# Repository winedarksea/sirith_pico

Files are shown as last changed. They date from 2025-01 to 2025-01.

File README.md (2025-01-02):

# Sirith Pico
#### Designed by Colin Catlin
#### License: CERN Open Hardware Licence Version 2 - Weakly Reciprocal
I ask only that you attribute me if you do make anything awesome with it, and more importantly, share with me as I would love to see others putting my hard work to good [use](https://syllepsis.live/2025/01/02/autonomous-ambush-missiles-and-my-first-circuit-board/). Feel free to reach out with any issues you run into.

This board was designed to do something standard dev boards cannot do: provide high power (12V, 60W) output with a microcontroller and a powerful rechargeable battery. It was designed to power something like a Raspberry Pi Zero, manage an array of servos, contain basic sensor data, log data to an SD card, and send and switch high power off board.

As a number of the ICs on this board are rather expensive, there is also a fairly extensive focus on circuit protections for power sources and GPIO pins, with the aim of reducing the probability of damage to the board.

This board went through countless digital versions, two expert reviews, and no less than 7 production variants. It was made by an amateur, but the design is well tested at this point. Amateur EMI testing was also done and indicated no major sources of unintentional radiation from the board.

Recommendations: switch the Fuse block on the "Batt Out" to PTC resettable fuse(s). The current fuses seem to not always contact the mounts fully.

Highlighted Capabilities:
* USB C Power Delivery Input up to 60W by default
* 2S or 3S Lipo Power and Charging
* Regulated and adjustable 8V or 12V system power
* Regulated 5V, 3.3V, and 1.8V power supply output
* User controllable output for high amperage output directly from battery*
* User controllable outputs for regulated system and 5V power
* Integrated i2c power monitoring circuit
* Integrated SD Card mount
* RP2040 Dual Core Microcontroller with 16 MB of flash memory
* IMU, Magnometer, Barometer
* RTC (if present)
* User-controllable status LEDs
* Pin layouts for connecting 4x 5V servos and 4x high voltage servos
* One 5V level shifted GPIO pin for communicating with devices such as LED light strips
* Footprint for Xiao or QtPy footprint boards for integration of wireless connectivity via UART to RP2040 (add on board not included)
* Integrated protection circuits on most system inputs and outputs
* Qwiic compatible connections of easy integration of other boards
* Assortment of board mounting options for 50 mm * 158.25 mm board

Primary Integrated Circuits (IC):
* RP2040 - primary microcontroller (MCU)
* MAX77960 - battery charger and system voltage regulation
* MPM54304 - 5V, 3.3V, and 1.8V buck regulator
* CYPD3177 - usb pd policy negotiations

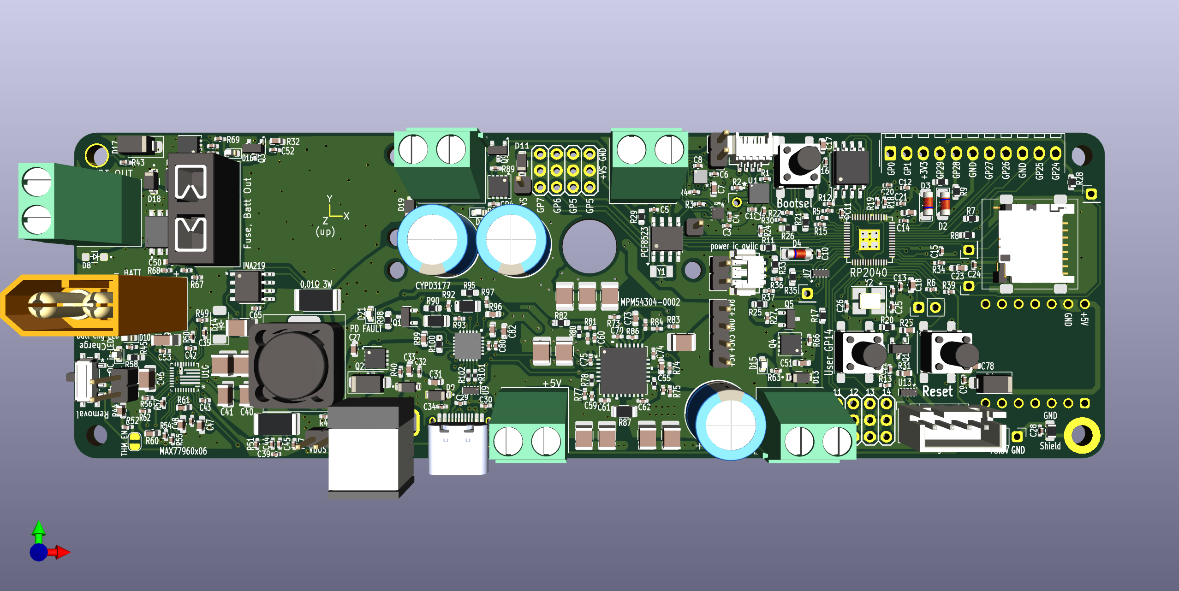
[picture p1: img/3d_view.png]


Note that by default interrupt pins are not directly connected to the RP2040 MCU in any way.

View documentation of the RP2040 from the Raspberry Pi Foundation for additional details on connecting peripherals and for excellent example tutorials.

MOSFET Power Outputs are connected to unidirectional TVS diodes which should provide inductive flyback protection in addition to transient overvoltage protection. The VBatt FET is additionally connected to a second Schottky diode for increased flyback protection.

For experimentation, it is recommended to begin by using GPIO 7, 28, and 29 as the series resistors and 3V3 Zener Diodes should prevent damage to the MCU from occurring in the event of many common misconfigurations and misconnections. 3V3 Zeners do not exactly maintain 3V3 volts, around 3.1V is often measured with the default GPIO pull up. These zeners may slightly alter the voltage and therefore ADC usage of GPIO28 and GPIO29. Note the 5V TVS diodes breakdown voltage is approximately 8V, these will be less protected than Zener diodes but also less restrictive.

For brevity, pins on the board are labeled GP instead of GPIO or only the number may be provided (ie 11 = GP11 = GPIO11). This should be considered functionally identical.

### System Power:

Primary system power delivery is through the device’s USB-C port. This port provides both data connection to the RP2040 IC as well as device power.  The CYPD3177 device is preconfigured by resistor dividers to negotiate for the highest available voltage up to 20V and 3A. This device can also be configured over i2c from the RP2040 MCU. If the device is only able to negotiate 5V power, the USB default standard power, the LED designated PD FAILURE on the board will be lit.

Power may also be provided through a dc barrel jack (not included, XXX has been used). If both dc barrel and usb c power sources are available, the higher voltage power source will automatically be used. This feature has been shown with limited testing to work for alternating between a 12V rated (~20V open circuit) solar panel and a 5V usb power supply.
Max recommended input is a well-behaved 24V power supply. Voltages above around 25V may  see the TVS over voltage protection beginning to conduct small amounts of power.

There are empty footprints under the DC barrel port for the addition of an LED and a series resistor, both 0803. This can be used to indicate power okay for this DC input and may also be useful to help pull down the open circuit voltage of any connected solar panels, if used.

A small test point header labeled VBUS should show the chosen power supply’s input voltage that will be received by the MAX77960.

### Battery Management

The MAX77960 provides battery charging and system voltage regulation with many inclusive features such as overcurrent protection and thermal shutdown. By default this is configured to use a 3S Lipo (three cell lithium batteries usually labeled 11.1V) with a regulated system max voltage of 12V and system current of 4 amps. By soldering the CNFG JP6 jumper on the bottom of the board, users may switch to a default configuration to 2S (two cell lithium batteries usually labeled 7.4V) at 8V system. The device WILL NOT automatically detect battery type. Connecting the incorrectly configured battery type may result in catastrophic battery failure. To double check the system’s current battery configuration, connect device without battery to DC power and use either the onboard INA219 or a voltmeter to measure Vsys. It should be around 8V in 2S configuration and around 12V in 3S configuration. Please refer to the MAX77960 datasheet for full details.

A sliding switch provides a battery disconnect override. The recommend procedure for battery connection using the XT60 connector is to have the switch in the disconnected position, insert battery, and then slide to charging position. To disconnect, perform in reverse first setting to disconnect then removing the battery. Whenever possible, avoid disconnect of batteries and dc power supply when the system is under significant power load, doing so could cause the board to malfunction. Not this switch does not necessarily trigger immediate battery charging, it merely signals charging enabled to the MAX77960 which proceeds to monitor battery and respond accordingly. While a battery is not needed for the board to function, including one will stabilize maximum power output of the device. In the event there are concerns about this switch accidentally being toggled, it can be removed leaving the device in a default state of battery charge enabled.

A small header labeled THM near the MAX77960 allows the connection of a thermistor. This is recommended if the device will be used in unregulated temperature environments as lithium batteries should not be charged in excessive heat or cold. To use, the THM_EN jumper must first be bridged. The R(resistance at room temp) value of the thermistor must match the value of the resistor R50, which is 10K. As setup, the pull down of ground, 110K on R41 will need to be removed for best accuracy, but should work as is (reading a bit hot). Beware if that resistor is removed a THM to GND thermistor must be present for device to function. In general, use a smaller Beta 10K NTC for a wider temperature cutoff. See MAX77960 datasheet for more info and example thermistor choices.

The INOKB output of the MAX77960 is connected to GPIO16 of the RP2040. This will be pulled low when a valid DC input is detected and can be used as a simple test for the presence of a connected external power source. The MAX77960 is also theoretically capable of reverse powering the USB C port with 5V power when configured to do so over i2c (off by default), but this functionality has not been tested on this board. STAT and INOKB pins from this device have test points on the bottom side of the board.

A pair of XXXX MOSFETs in parallel provide a high-side switchable output from the battery through a mini automative blade style fuse for overcurrent protection. While this has been designed with a target current output of 30 amps, extreme care should be and system monitored for shorts and excessive heating of the board gpiven the high discharge capacity of most lithium ion batteries. Also be aware that the board, which has a default fast charging current of 400 mA, will take much longer to charge the battery than the rate at which it can be discharged. Faster charging rates may be selected by adjusting RX or over i2c.

The system does not include a battery cell balancer. The use of a default 12V max voltage (approximately 80% of capacity) and a slow (for large batteries) fast charge rate of 400 mA should minimize the need for balancing, but cell balancing is still recommended when possible. 

A battery level gauge is also not included. When on battery power, the INA219 can be used to directly monitor the battery voltage and closely approximate battery level. As the default undervoltage protection for the system is lower than ideal, it is highly recommended that users relying on battery power for their systems power down their systems programmatically when a low voltage on the battery is reached to prevent possible battery damage.

Beyond the battery voltage, system regulated voltage (Vsys) from the MAX77960 passes through the INA219 current/voltage/power monitor with a 0.010 ohm resistor which can be read over i2c. Overcurrent protection kicks in after 4 amps but can be configured in the MAX77960 by i2c to be as high as 10 amps. Vsys will follow battery voltage when battery is charging or discharging.

The Vsys has another high side, GPIO-controlled MOSFET switch which can be used to enable or disable power output to an external device. Vsys also has placement for additional bulk capacitance to be installed by the user if needed, to further reduce volatility of the output power.

Vsys has several output connections. Note GPIO5 pin in this section is intentionally duplicated, allowing for synchronous output if needed.

The MPM54304 is powered from Vsys and produces additional regulated power outputs. Note that this IC is the usually hottest on the board, and that care and an additional heatsink is recommended. Note that the device does include automatic thermal shutdown in the event of excessive heat generation but this does not engage until 160°C. Additionally, running the system on a 2S battery setting will reduce heating as the voltage drop will be lower, and this is recommended when a 3S battery is not otherwise needed.

Theoretical max power output o MPM54304 is 6A for 5V, 3A for 3V3 and 3A for 1V8, however this may be limited further by the maximum continuous power dissipation due to thermal limits. To maximize performance, provide a larger heatsink and use a lower input voltage (2S configuration). For further details review the manufacturer’s datasheet for the MPM54304.

It is recommended to have inline resistors or PTC fuses on power lines going off board, especially on the 3V3 line which controls the MCU, to avoid brownouts from external shorts, as the overcurrent protection on the MPM54304 will take down the entire power net in the event of a short. The Power Good pin from this IC is connected to a circular test point on the bottom of the board.

### Board Footprint

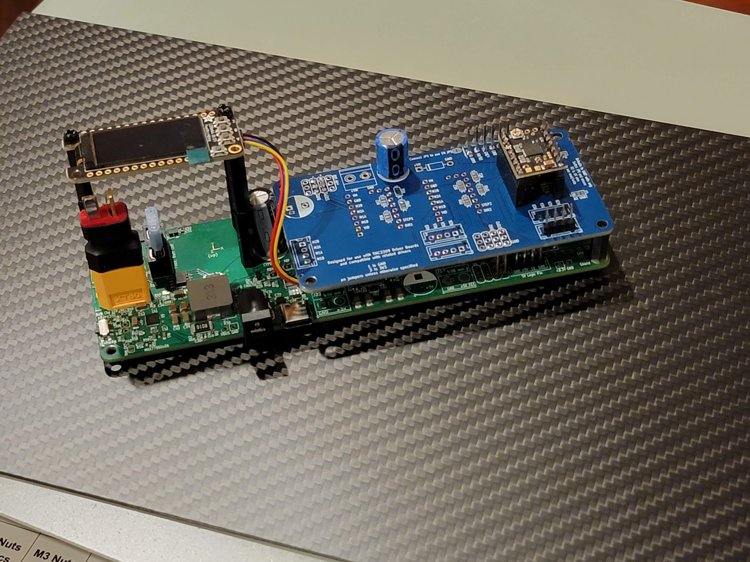
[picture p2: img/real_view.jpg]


The four layer printed circuit board measures 50 mm * 158.25 mm. Mounting holes for M3 screws are present on all four corners. The connections of these are rather irregular. Two are unplated through holes with no copper connection. Two others are plated through holes which should provide more resistance to wear and tear. One, located in the VBat section of the board, is connected to board ground by a 1M Ohm resistor. The other in the opposing corner near the QTPy/Xiao footprint is connected to ground by a capacitor with an adjacent footprint for an additional capacitor, resistor, or ferrite bead if desired, that plated through hole is also connected to USB shield, if present.

### QTPy/Xiao

A footprint designed to be compatible with most Adafruit Industries QTPy or SeeedStudio Xiao layout development board exists on the bottom of this board primarily intended for adding some wireless connectivity, if desired. These devices may be soldered directly or using pin headers, double checking proper alignment. Only four pins of the attached board are connected to the MCU. 5V power provides power to the 5V/USB power of the device through a Schottky diode, resulting in a minor voltage drop (no issues have been observed as result of this voltage drop) and allowing simultaneous connecting of the smaller board with USB. GND is also connected as well as the TX and RX pins of the device enabling communication with pins 24 and 25 of the RP2040 (see Table 1).

### Programming the Board

Programming the board should be identical in most ways to programming a Raspberry Pi Pico. BOOTSEL is held down while the device is plugged into the USB port of a host device to allow installation of UF2 boot files on initial setup. All UF2 files compatible with Raspberry Pi Picos should be compatible with this device, although note that pin aliases in the device software, such as “LED” pin will not align with a board LED.

### i2c addresses
* 0x08 = CYPD3177
* 0x3C = display, if connected
* 0x40 = INA219
* 0x68 = MPM
* 0x68 = RTC
* 0x69 = MAX probably

* 0x68 = RTC
* Ox77/Ox76 = BMP390
* 0x1C = LIS3MDL
* 0x6A = LSM6DSOX

### Table 1: GPIO Functions
| **Pin/Output**  | **Functions** | **Onboard Protections/Connections** |
| --- | --- | --- |
| RP2040 GPIO 0 | General purpose, labeled TX | 27 Ohm series resistor |
| RP2040 GPIO 1 | General purpose, labeled RX | 27 Ohm series resistor |
| RP2040 GPIO 2 | I2C 1 SDA for Sensors, ‘sense qwiic’ | 27 Ohm series resistor, 4K7 Ohm pull-up to 3V3 |
| RP2040 GPIO 3 | I2C 1 SCL for Sensors, ‘sense qwiic’ | 27 Ohm series resistor, 4K7 Ohm pull-up to 3V3 |
| RP2040 GPIO 4 | Enables Vsys MOSFET and LED when pulled high, | 330 Ohm series resistor, 1M Ohm pull down to GND |
| RP2040 GPIO 5 | Vsys header, duplicated with two positions on output header | |
| RP2040 GPIO 6 | Vsys header, single header | |
| RP2040 GPIO 7 | Vsys header, single header | 330 Ohm series resistor, 3V3 Zener to GND |
| RP2040 GPIO 8 | I2C0 SDA, ‘power ic qwiic’, connected to board power ICs | 27 Ohm series resistor, 4K7 Ohm pull-up to 3V3, 5V TVS diode |
| RP2040 GPIO 9 | I2C0 SCL, ‘power ic qwiic’, connected to board power ICs | 27 Ohm series resistor, 4K7 Ohm pull-up to 3V3, 5V TVS diode |
| RP2040 GPIO 10  | Enables 5V MOSFET/+5VF when pulled high, also with additional header near SD card enclosure, also can be used as status LED | 330 Ohm series resistor (between header and MOSFET, not between header and MCU), 1M Ohm pull down to GND, 5V TVS diode |
| RP2040 GPIO 11  | Header near system 5V outputs | 330 Ohm series resistor and 5V TVS for surge protection |
| RP2040 GPIO 12  | Header near system 5V outputs | |
| RP2040 GPIO 13  | Header near system 5V outputs | |
| RP2040 GPIO 14  | Header near system 5V outputs | Connected to button, can be programmed as an input |
| RP2040 GPIO 15  | 5V Logic Level GPIO, level shifted by BSS138 with 110K Ohm pull-up to 5V | 330 Ohm series resistor |
| RP2040 GPIO 16  | INOKB to MAX77960<br>pulls low when DC power present, floating when disconnected | |
| RP2040 GPIO 17  | Enables VBatt MOSFET and LED when pulled high | 330 Ohm series resistor, 1M Ohm pull down to GND |
| RP2040 GPIO 18  | CLK pin of SD Card | |
| RP2040 GPIO 19  | CMD pin of SD Card | |
| RP2040 GPIO 20  | DAT0 of SD Card | 10K pull-up to 3V3 |
| RP2040 GPIO 21  | DAT1 of SD Card, additional header near SD card when unused | |
| RP2040 GPIO 22  | DAT2 of SD Card, additional header near SD card when unused | |
| RP2040 GPIO 23  | DAT3/CD of SD Card | |
| RP2040 GPIO 24  | Two connections, to header and to RX of QTPy/Xiao footprint, so is TX of MCU when used | 330 Ohm series resistor |
| RP2040 GPIO 25  | Two connections,to  header and to TX of QTPy/Xiao footprint, so is RX of MCU when used | 330 Ohm series resistor |
| RP2040 GPIO 26  | Header | |
| RP2040 GPIO 27  | Header | |
| RP2040 GPIO 28  | Header | 330 Ohm series resistor, 3V3 Zener to GND |
| RP2040 GPIO 29  | Header | 330 Ohm series resistor, 3V3 Zener to GND |
| SWDIO and SWCLK | Debugging connections for RP2040 | |
| INT | Connection to interrupt pin from device IMU | |
| INT MAG | Connection to interrupt pin from device manometer | |
| INT/CLKOUT | Connection to interrupt/clkout pin from device RTC, if present | |

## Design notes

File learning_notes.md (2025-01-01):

## Loosely Collected Notes I took as I learned circuits and designed this board

Servo Controller (ala Adafruit) 
	PCA9685
	tlc59116
	use a pi pico or similar, but more programming work
Servo Battery
	ETA9740, HM5907
	6V 4A regulated power supply to protect servo
		Boost converter or regulator (5V to 6V with a resistor)  (TI has a bunch)
	Include 5V power
	Includes 3.3 V power
Servo battery charger
	TPS61230 (5A)
	TPS61090 (2A)
	https://wiki.seeedstudio.com/Lipo-Rider-Plus/
	2S BQ25887 2S Balance charging IC
USB-c wiring:
	the correct pulldowns for CC1 and CC2 are 5K1, You do need separate pulldowns for each CC pin
	DP and DN should go straight to the data controller (potentially with ESD protection diodes).
	There should be no more than 10uF of capacitance on VBus, and you have to make sure your circuit draws no more than 100mA until:
    1. you negotiate more through power descriptors (up to 500mA)
    2. you see appropriate voltages on the CC lines
    3. you detect either a DCP or CDP using BCS
	https://dubiouscreations.com/2021/04/06/designing-with-usb-c-lessons-learned/
	It looks like I should have fed CC1 and CC2 to two adc pins to handle connector polarity.
	Basically, if you see >1.23V on either CC1 or CC2, you are all set and can draw 3A. If it's between 0.66V and 1.23V you can draw 1.5A. Put a filter on the CC lines because there will be some fluctuations (up to 10ms long) that you are supposed to ignore.
	You need to also verify the IC connected to the UDP pin has an internal pull up to 3.3V, or add an external resistance.
	Suggestion seemed to be capacitor placed as close as physically possible to power output pins.
	Shield should not be connected to the ground, but the chassis.
	USB 2.0-only SMT Korean Hroparts TYPE-C-31-M-12 (LCSC part number C165948)
	Pico USB_DM and USB_DP A 27Ω series termination resistor is required on each pin, but bus pullups and pulldowns are provided internally
Voltage Regulation
	USB SHIELD: 1MΩ resistor and 4.7 nF capacitor in parallel  OR (330 Ω resistor and a 0.1 µF capacitor in parallel)
	213716 Molex USB C
	AP2112  (input to 3.3V)  OR identical Torex XC6210B332MR-G

For 1S Lipo: MCP73871

MCP73213 or MCP73223 would require 2 LDO (one for USB one for battery)
JST-XH 2S
bq241xx  (rather complicated wiring)

Ultra Librarian or SNAPEDA

4.7K resistor on SDA and SCL for high speed operations  (2K fine, probably better if some are expected on upstream board)
Capacitors. Near each power line for IC.The value it is not very critical and usually it is at the range of 0.001μF to 4.7μF, but the combination of values helps to keep the impedance low and to avoid resonance spikes. 100nF and 10uF

Absolute Orientation Sensor
	BNO055 BNO08X (not in stock?)  (2.4 to 3.6V)
		0x29 (Com3 adjusts to 0x28)

qwiic connector  (JST SH 4-pin connector and will only use it for I2C)
	servo and absolute orientation sensor

Altimeter
	Bosch BMP390  (1.2 to 3.6V)
		SDO to GND results in slave address 1110110 (0x76); connection it to VDDIO results in slave address 1110111 (0x77)

https://www.nxp.com/design/designs/kv-series-quad-motor-control:KINETIS-DRONE-REFERENCE-DESIGN
https://www.nxp.com/design/designs/ai-robot-platform-based-on-i-mx-8m-plus:AI-ROBOT-PLATFORM
https://www.nxp.com/design/designs/px4-robotic-drone-vehicle-flight-management-unit-vmu-fmu-rddrone-fmuk66:RDDRONE-FMUK66
https://www.ti.com/solution/drone-propeller-esc?variantid=17140&subsystemid=17313
https://www.ti.com/applications/industrial/motor-drives/overview.html
https://www.ti.com/solution/drone-propeller-esc?variantid=17141&subsystemid=17228

N-channel Mosfet to PWM (terminal block)  (high current switch)
	D is the thing being used (Power source -> thing used -> Mosfet -> sink)
	Gate is the PWM signal (R1 1k, C1 100u, R2 10k)
	https://www.instructables.com/How-to-Control-a-MOSFET-With-Arduino-PWM/
	https://forum.arduino.cc/t/mosfet-control-with-pwm/912521/7
5 V Mosfet for powering on Vision board
Mosfet with no voltage (connecting RUN or GLOBAL_EN to ground)

Voltage of all on I2C ??
Addresses of all

Fiducial markers (for pick and place)

Include a charging LED (off when charged)

Wireless Receiver: SX1280
Add wifi ESP module

Battery linked to power switch
Microcontroller power on Vision Processor (what signal?) (GPIO pin 3, or serial message, RUN to ground)

RP2040 Chip
	USB_VDD should be decoupled with a 100nF capacitor close to the chip’s USB_VDD pin
	To reduce the number of external power supplies, ADC_AVDD can use from the same power source as the digital IO supply (IOVDD)
	ADC_AVDD should be decoupled with a 100nF capacitor close to the chip’s ADC_AVDD pin
	(all of the above and more to the same 3.3V)
	IOVDD should be decoupled with a 100nF capacitor close to each of the chip’s IOVDD pins.
	DVDD should be decoupled with a 100nF capacitor close to each of the chip’s DVDD pins.
	A 1μF capacitor should be connected between VREG_VIN and ground close to the chip’s VREG_VIN pin
	USB 2.0 compatible Full Speed device (12Mbps)

Mount points (for vibration dampening)

Microcontoller Connections:
	Two buttons (any pin, pwm)
		servo latch
	1 serial to MCU
		send data, receive updated target
	8 MB SPI FLASH (or larger) (QSPI NOR memory)
		Winbound W25Q16  W25Q16JVSSIM
	12 MHz crystal for perfect timing
	USB (same both for charging lipo and serial)
	BOOTSEL button while plugging it into USB (or pulling down the RUN/Reset pin to ground)

Pico Alternatives:
	STM32F779AIY6TR
	MSP432P411xT / MSP432P401xT
	nRF5340
	Kinetis® KV4x family - MCU for motor control
		MK20DX32VLH5 MKV42F128VL

Future Directions:
LoRa
DC input to Charge Lipo and to Power board (if connected)
	5V 2A switching regulator for robust power supply (8V -18V input voltage)

Suppliers:
	JLCPCB
	PCB Shopper
	PCBWay
	SeeedStudio
	Smart Prototyping
	PCB Shopper - see all

Reflow Oven:
	Breville Smart Oven
	T-962 https://www.aliexpress.com/item/2251832137689249.html?gatewayAdapt=4itemAdapt 
	ZH2520HL (needs 110V) https://zbdz.en.alibaba.com/product/62345546771-915115390/Smt_Reflow_Oven_For_IC_Chip_Mini_Reflow_Soldering_And_Welding_Oven.html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 

BGA makes assembly much more expensive

Actual Part List:
	USB4085-GF-A
	JST B3B-XH-AM(LF)(SN)  (right angle S3B-XH-A(LF)(SN) out of stock)
	Resistors 0603 (larger allows routing UNDER)
		5.1K  - 2
		R0 (no resistance)

	BATT CHARGER 
reqs: 
	2S or 3S Lipo (3s preferred)
	VIN Min < 5V
	VIN Max > 20V
	Current > 5 Amps
options:
	MP2650/MP2760  (unavailable)
	MP2762A (2s only)

	MP2639AGR-Z (QFN)
	MP2672A or MP2639A (QFN) or MAX14748 (non stocked)0x0A, integrates CC negotiation) or MAX77962 (0xD2h/0xD3h) or TI bq25792 (QFN) 		
	bq24179 (not stock)
	bq25887 (best stock, psel for detection), bq25883, bq25882, bq25886 (~886 best but not stocking, detects BC1.2)
	ACT2861QI301 (good for 3 cell, QFN, available)
	BQ25792
	MAX77961 (3 cell, sys connection, QFN) (61 is 6A, 60 is 3A)

	STUSB4500 (WLSCP, no stock) or STUSB4500L (3A Max) or MAX77958 or TPS65987D or PTN5110 or UPD301C
		MAX77958 is good but not QFN
	TPS65987D (QFN) (and similar tps65983 but external switch for 5A)
	XPD319BP25 (36W)

	BHI260AP (LGA 44 pin, 1.8V)  BHI160 (LGA 24 pin, 1.6 to 3.6V	)
	BMP390/BMP384/BMP581 (LGA 10 pin, 1.6 to 3.6V)
	BMM150 (WLCSP-12, 1.6-3.6V)
	BNO086, FSP200 (similar or same as Bosch, low stock)
	ICM-42688-V(QFN package, no sensor fusion)
	ICM-20948 (no stock, QFN, sensor fusion included but questionable)
	ISM330DHCX + LIS3MDL (6+3 axis, LGA, industrial, low stock) - add magnetometer and rp2040 for Fusion calculation

	PWM Controller PCA9685 (), TLC59116F (VQFN or TSSOP), TLC5947 (RGB LED Drivers)TLC59711, TLC5940, TLC5946, TLC694x, TLC59711 
		TLC5971, LED6001, MAX16803, RT9288A, LT3595A and LT8500, tlc59282 (all at once driver)
		LT8500 and TLC5940 are confirmed motor control,
		Dedicated Pi Pico (16 bit) - https://www.waveshare.com/w/upload/0/06/Pico_Servo_Driver_Sch.pdf 
		STNRG388A

	MOSFET: PMPB10XNE PMPB11EN CSD18542KTT

	BUCK
		All in one: lm5127, ADP1034/ADP1031, ltc7811/7818/7817, 
		tps65310a (2A limit, no stock),
		tps65287 (low stock, uncertain voltage setting but likely 3 buck),
		MAX20028 (only one > 4V, moderate stock), 
		MPM54304 (non over 5.5V, LGA, moderate stock)
		NCV97200 (3.3 and 5V only, no stock)
		ADP5055 (high current, LGA, moderate stock, 18V max)
		MC34VR500 (QFN, moderate stock)
	Plain BUCK
		MAX17504 (3.5A wide voltage)
		MAX17541G (0.5A)
		LMR16006
		TPS65320D-Q1 (buck + loo)
		MP2223 (dual output buck)
	Tps54331, MAX20028, MPM54304, TPS54620 (6A, in stock)

	DC Motor Driver: TB6612, DRV8871, L293D, L9110H, MX1508 (make pi), DRV8840, DRV8313, UCC27200A
	L298N, L293D, SmartElex 15S, VNH2SP30, VNH3ASP30, TB6612FNG, TB67H450FNG, L6258, HR8825
	FROM 3D Printers: TMC2209, TMC2130, TMC2225
	https://learn.adafruit.com/assets/9536
	https://www.ti.com/lit/ug/tiducn7/tiducn7.pdf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
	https://www.ti.com/tool/TIDA-00827#description 

https://www.mouser.com/manufacturer/amphenol-ltw/

JCLPCB In Stock:
	RP2040
	BMP388
	TMC2209
	BMM150
	BHI160B
	BQ7693003DBTR (Cell balancing)
	Bucks: TPS54331DR, MC34063ADR2G (1.5A), ICL7660AIBAZA-T
	LDO AMS1117-3.3 (3.3V fixed)
	Mosfets: AO3401A (max 12 V on gate, 4A), AO3400A (5.7A) P-channel,
	N-channel AO3402 (4A)
	USB PD-controller: XPD319 (DRP only), CYPD2120-24LQXIT
	PWM Controller: PCA9635, TLC5940 (no stock), TM1640, HT1621B
	Charger: MP26123DR
External:
	tps65987d
	TLC59401
	MAX77961EFV06+
	MAX17205

Used Datasheets:
y

Connectors:
neutrik
Phoenix Contact

Reqs:
47μF (1206 or 1210), 16V  GRM31CR61C476ME44, EMK325ABJ476MM8P
10 uF (0805), 16V  (Murata GRM32ER7YA106KA12)
10 uF (1210), 35V
220 nF   (0402), 6.3V
4.7 uF  (0402), 6.3V (10V on batt EVAL)
47 nF (0402) (25V on battery inrush) (Murata GRM31CR61C476ME44)
100 nF (0402), 10V  (>12V for batt)
22 uF (), 6V  GRM21BR61C226ME44 (overkill)
10 nF (25V on USB)
220 nF (on Inductor, low V, EVAL 0402)
22 pF (crystal, stable C0G class)

Mostly MLCC
X5R or X7R (especially on BATT charge and Converter for low ESR), although Class 1 is best
bigger size footprints generally are more stable with same temp coef
Anything on SYS, and BATT can be 16V MAX:   22UF (1210)
6V: 4.7uF (0603), 220 pF, 
33 pF (6V, Class 1)
47 uF (Sys, 2220)
VBUS, VD (PP_HV1) can be 30V MAX: 10 nF (0402), 1uF (0603), 10uF (1210), 47nF (0603)
Also 10uF 0603

3.3 uH  (16.3 mΩ resistance DC, 15 Amp, 10 Amp (+ 40C rise) (Pulse PA5007.332NLT)

0.01 Ω (1206), 3W
10 ohm (0402 on datasheet) 0.1W or higher
4.7 Ω (0402)
200K Ω (0402)

17800 (inlim)
86600 (iset)
178000 (ITO top off)
226000 (ITO top off)
178000 (set)
226000 (set 12.0 V)

Diodes
PMEG4050EP

LED: 19-217/GHC-YR1S2/3T

Mosfet
10A DMN3016LFDE DMN3020

Gate to Source should be 12V
for 5V: 5A is needed
for Sys: 10 A is needed
for Batt: 30A is needed

NOTES:
	Don’t unplug under load, either battery or DC power
	GP and GPIO are used interchangeably
	Use the batt removal switch
	This switch can be removed if there are concerns about accidentally sliding it to removal as the default is to charge (or remove what is currently R43, the pull up to AVL)
	Using a thermosistor - the R(resistance at room temp) value must match the value of the resistor R50 (currently 10K). As setup, the pull down of ground, 110K on R41 will need to be removed for best accuracy, but should work with (reading a bit hot). Beware if that resistor is removed a THM to GND must be present. See datasheet for more info and example thermistor choices. Use a smaller Beta 10K NTC for a wider temperature cutoff.
	Remove 10K on GP15 and bridge
	Fuses can be removed to slightly lower quiescent current or diodes can be desoldered
	can place heatsinks on square test pads
	avoid placing directly on conductive sheets as it will short test pads
	can use the vbus header to provide DC in if no USB power or USB out
	batt should be connected, it acts as an extra source of power for spikes
	batt can be kept in protective sleeve, but default charge is low current
	could use the places for capacitors on batt out and sys as locations for terminal blocks (caps on batt should have connections for high-ish amps, others maybe not so high)
	no batt balancing as default charge is slow
	no battery gauge!
	three sets of sda and scl i2c pins, all with pull ups to +3V3
	PP_HV2 has 5V supply theoretically capable of supplying/sourcing devices over USB, but by default this is disabled and on power loss will reset to sink mode
	battery low voltage
	all power chips have built in thermal shutdowns and overcurrent/undervoltage protections
	could replace the CNFG Resistor (currently R43) from 8660 (3S) to 86k6 (2s)
	Use on lead acid: https://www.ti.com/lit/an/slua992/slua992.pdf
	2 issues with RP2040: no floating point unit, no code security (use another board if those are needed for that and use this as a relay)
	INOKB is attached to GPIO 16 of the RP2040. This means this can be used to detect the presence of DC power on CHGIN when this is pulled low (and is pulled high when disconnected). Note that due to the default pull down of the RP2040, the test point for this will always register ground, just ground high resistance (>200K) with no chargin, and to low resistance to ground with charging present
	solar panel goes to high voltage (shutting off input from usb) even when there is little current available. The charger can sometime deal with this by regulating system voltage, but only if it has a battery connected for backup power.
	set i2c lines high to reduce current loss slightly (as they have 3.3V pull up resistors)
	set 5v logic pin high to reduce current loss
	swap current limiting resistor on 5V GP15 to get a high power data line (it’s bigger than its neighbors, an 0603 rather than 0402)
	Note the sum of current limiting resistors, if all were on, would still exceed the total current producible by the RP2040
	there is a lot of capacitance on this board, expect it to take a while (seconds) to fully turn off
	A high quality 3S lipo can theoretically produce something like 500 Amps, that is power that can be quite dangerous
	MOSFET max on DMP3007SCG is 50A continuous current and TPH3R704PL is 90A, Mini fuses are available up to 30A and the fuse block holder is rated to 20 Amps @ 500V AC, with all four layers (2x power, 2x ground) exclusively with power planes to hold the current on that corner of the PCB
	What is a safe temperature? In general components here have ratings provided for 70C with max ratings usually being higher. So that should be a guidance for what a safe ‘hot’ limit is. Lower, however, is definitely preferred as hot temperatures will likely result in a much short product lifespan
	The MPM will get less hot in 2S lipo mode (lower input voltage)
	Use temperature sensor to shut off charging if too hot
	can use a solar panel as dc input, keep in mind that panels rated voltage is often exceeded at open circuit, so 12V safest. Same with batteries, a ‘24V’ battery often has a nominal voltage as high as 30V
	So how much above 24V is a problem? See if the TVS diode near the barrel jack starts to get hot. TVS can repeated handle current in small amounts, but heat can damage it over time.
	square test points for heat sinks as needed
	Remove the voltage sensing resistor next to INA219 to further reduce power loss
	having inline resistors or PTC fuses in power going off board is a good idea, especially on the 3V3 line which controls the MCU
	LEDs are of varying brightness, batt mosfet is very bright (warning) while vsys mosfet is very dim
	Zeners may slightly alter the voltage and therefore ADC usage of GP28 and GP29
	The diode by the Vsys MOSFET could be removed for adding items there if desired
	Note on the two plated through holes, which should be preferred for connecting as they are more resilient. One connected to USB shield with option to connect to ground, the other connected to ground with 1M
	i2c line 1 (sensors) doesn’t have full ESD protection, although i2c0 does have 5V tvs (power ic qwiic)
	an LED and resistor (0805) may be placed on the bottom near DC in if a connection indicator is desired, or to pull down open circuit of a solar panel
	Place a diode (currently D15) between VBAT and VSyS to increase the possible current maximum
	Careful about using metal screws on the mounting holes as there are traces and planes fairly close to some of them. If screws are connecting to another board or metal enclosure, something conductive, keep an eye on them.
	Thinking about the supercap is that in the event of a power loss (probably a thermal overheat or overcurrent protection engagement) the MCU could continue to function (check for loss of connection to 5V powered INA219 for power loss)
	Theoretically MAX can be used to send reverse 5V OTG, if DC is not connected.
	Battery helps absorb inductive loads
Low Battery:
	Remove Diode and let Sys shut down automatically, adjust Sys min
	Set UVLO on MPM to 8.5 volts, and/or turn off 5V bucks (en1/2) but 
Note about Zeners and how they don’t hold exactly a stable 3V3 like you might hope. Yes, you can safely remove them (carefully, of course).
keep 3V3
	could pass 12V directly into VSYS (or indeed 5V to 16V)
	Stop performing actions on all outputs
	Use a timer since chg-in last connected
	DC in barrel has a TVS with a minimum possible breakdown of 24.4V
Possible substitutions:
	MAX 77960 (3A max charge in, 6A max sys)
	MPM54304GMN -XXX other suffixes (5V may be 2 separate nets, 3A max each)
	TPS25750 (would require some rework)
	Different RP2040 flash memory sizes
	Different switches, diodes, mosfets, inductor
	Any BMP38X, BMP581
Not populated if no equivalents available (all should be hand solderable):
	Fuse blocks
	SD card mount
	JST connectors
	Mounting holes changed
Pair with a ATECC608 breakout for code security, or use a code security feature on the Xiao/QTpy breakout spot

0x08 = CYPD3177
0x23 =TPS probably
0x3C = display, if connected
0x40 = INA219
0x68 = MPM
0x68 = RTC
0x69 = MAX probably

0x10 = BMM150
0x68 = RTC
0x68/Ox69 = BMI270
Ox77/Ox76 = BMP390

Uses:
	Uninterrupted backup power supply
	Boost power supply (where occasional spikes above USB power capability, legacy won’t cut it)
	Robots and automation of all sorts (ideal as sensors, unified power and mcu)

21.4 47.1
STEPPER BOARD
2 wire 16AWG standard cable
	either a AMP Mate-n-Lok 1-480424-0 power connector
	or PCIE or ATX 12V-only
	JST VH 4 pin (5v red, gnd, gnd, 12v yellow)
	molex sata 675820000
8 pin connector 
3x 5 screw terminal
Diodes:
https://learn.watterott.com/silentstepstick/protector/
https://www.autodesk.com/products/fusion-360/blog/trace-width/

Lessons:
	Use planes more than wires (although wires override planes and can help manage lane prioritization)
	Use the grid
	Use ‘Vendor’ for JCLPCB number in Kicad to export BOM easily
	voltage rating on capacitors should be 2x average expected
	use lots of capacitors (except on very high speed lines)

i2c pull-ups (those for I2C1 are not shown in image but are present) are to 3V3 power external and not to LDO_3V3 (assume this doesn’t matter but perhaps they need to be in a valid state at boot?)
LDO 1V8 has higher capacitance than recommend (max 6 uF, 10 uF used)
5V on PP_HV2
Pins 57, 58, and 59 for drain and grounds are labeled differently than data sheet (matching 59, 58, 57) but are correctly matched in layout

3V3 and 5VD come from a regulator and become available slightly after system receives power

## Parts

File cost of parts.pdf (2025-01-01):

PCB Prototype & PCB Fabrication Manufacturer - JLCPCB | https://cart.jlcpcb.com/smtQuote?pcbFileNo=1eeebdad9bf540228a708...

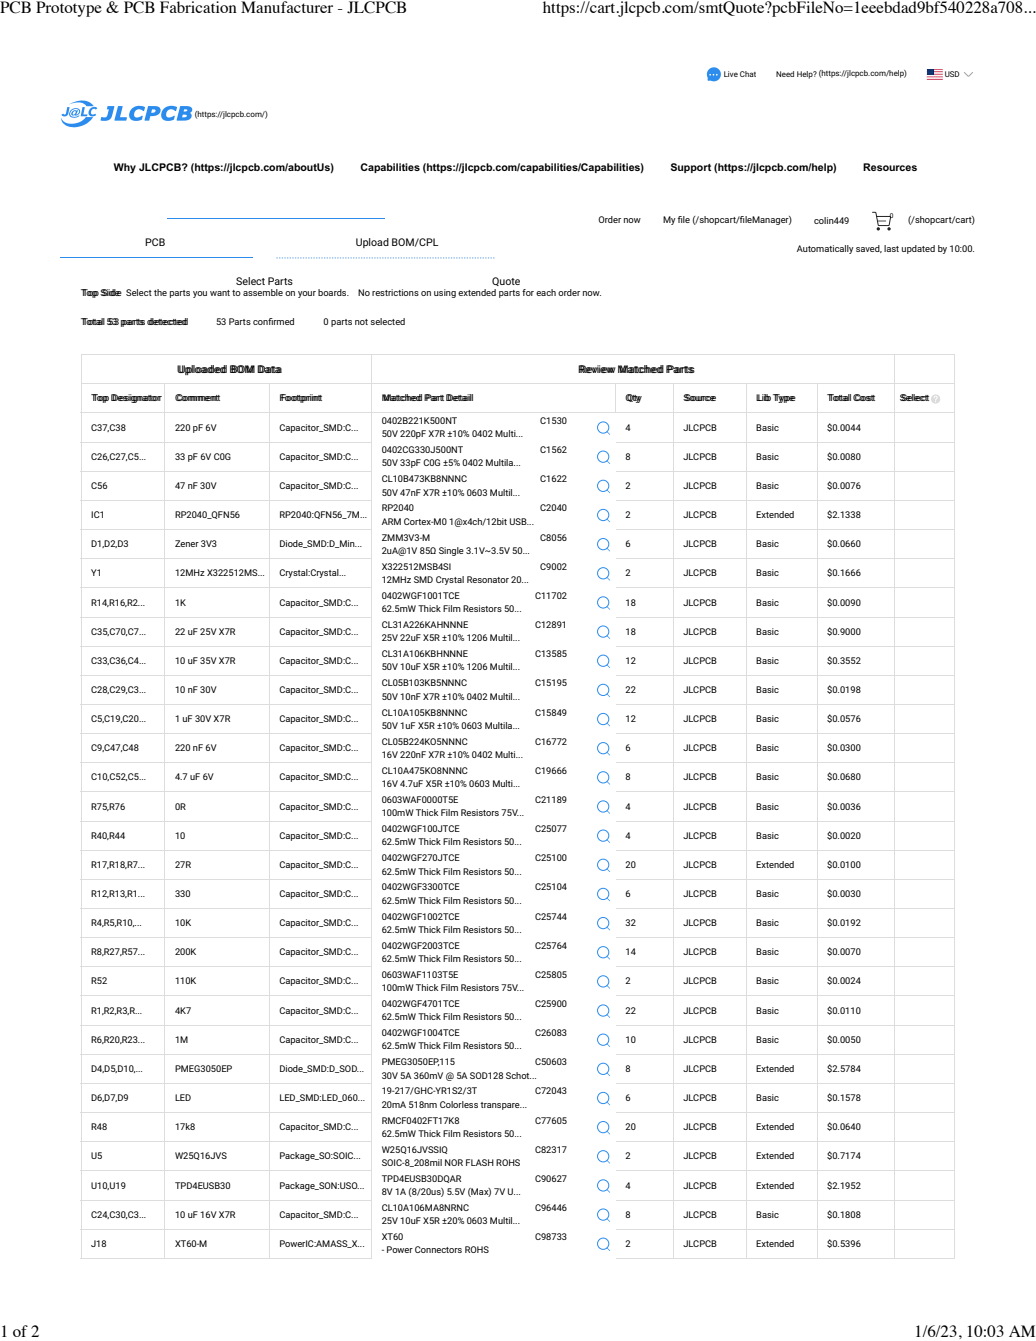
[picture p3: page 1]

Automatically saved, last updated by 10:00.

TToopp SSiiddee Select the parts you want to assemble on your boards. No restrictions on using extended parts for each order now.

Uploaded BOM Data | Review Matched Parts

Top Designator | Comment | Footprint | Matched Part Detail | Qty | Source | Lib Type | Total Cost | Select

C37,C38 | 220 pF 6V | Capacitor_SMD:C... | 0402B221K500NT C1530 50V 220pF X7R ±10% 0402 Multi... | 4 | JLCPCB | Basic | $0.0044

C26,C27,C5... | 33 pF 6V C0G | Capacitor_SMD:C... | 0402CG330J500NT C1562 50V 33pF C0G ±5% 0402 Multila... | 8 | JLCPCB | Basic | $0.0080

C56 | 47 nF 30V | Capacitor_SMD:C... | CL10B473KB8NNNC C1622 50V 47nF X7R ±10% 0603 Multil... | 2 | JLCPCB | Basic | $0.0076

IC1 | RP2040_QFN56 | RP2040:QFN56_7M... | RP2040 C2040 ARM Cortex-M0 1@x4ch/12bit USB... | 2 | JLCPCB | Extended | $2.1338

D1,D2,D3 | Zener 3V3 | Diode_SMD:D_Min... | ZMM3V3-M C8056 2uA@1V 85Ω Single 3.1V~3.5V 50... | 6 | JLCPCB | Basic | $0.0660

Y1 | 12MHz X322512MS... | Crystal:Crystal... | X322512MSB4SI C9002 12MHz SMD Crystal Resonator 20... | 2 | JLCPCB | Basic | $0.1666

R14,R16,R2... | 1K | Capacitor_SMD:C... | 0402WGF1001TCE C11702 62.5mW Thick Film Resistors 50... | 18 | JLCPCB | Basic | $0.0090

C35,C70,C7... | 22 uF 25V X7R | Capacitor_SMD:C... | CL31A226KAHNNNE C12891 25V 22uF X5R ±10% 1206 Multil... | 18 | JLCPCB | Basic | $0.9000

C33,C36,C4... | 10 uF 35V X7R | Capacitor_SMD:C... | CL31A106KBHNNNE C13585 50V 10uF X5R ±10% 1206 Multil... | 12 | JLCPCB | Basic | $0.3552

C28,C29,C3... | 10 nF 30V | Capacitor_SMD:C... | CL05B103KB5NNNC C15195 50V 10nF X7R ±10% 0402 Multil... | 22 | JLCPCB | Basic | $0.0198

C5,C19,C20... | 1 uF 30V X7R | Capacitor_SMD:C... | CL10A105KB8NNNC C15849 50V 1uF X5R ±10% 0603 Multila... | 12 | JLCPCB | Basic | $0.0576

C9,C47,C48 | 220 nF 6V | Capacitor_SMD:C... | CL05B224KO5NNNC C16772 16V 220nF X7R ±10% 0402 Multi... | 6 | JLCPCB | Basic | $0.0300

C10,C52,C5... | 4.7 uF 6V | Capacitor_SMD:C... | CL10A475KO8NNNC C19666 16V 4.7uF X5R ±10% 0603 Multi... | 8 | JLCPCB | Basic | $0.0680

R75,R76 | 0R | Capacitor_SMD:C... | 0603WAF0000T5E C21189 100mW Thick Film Resistors 75V... | 4 | JLCPCB | Basic | $0.0036

R40,R44 | 10 | Capacitor_SMD:C... | 0402WGF100JTCE C25077 62.5mW Thick Film Resistors 50... | 4 | JLCPCB | Basic | $0.0020

R17,R18,R7... | 27R | Capacitor_SMD:C... | 0402WGF270JTCE C25100 62.5mW Thick Film Resistors 50... | 20 | JLCPCB | Extended | $0.0100

R12,R13,R1... | 330 | Capacitor_SMD:C... | 0402WGF3300TCE C25104 62.5mW Thick Film Resistors 50... | 6 | JLCPCB | Basic | $0.0030

R4,R5,R10,... | 10K | Capacitor_SMD:C... | 0402WGF1002TCE C25744 62.5mW Thick Film Resistors 50... | 32 | JLCPCB | Basic | $0.0192

R8,R27,R57... | 200K | Capacitor_SMD:C... | 0402WGF2003TCE C25764 62.5mW Thick Film Resistors 50... | 14 | JLCPCB | Basic | $0.0070

R52 | 110K | Capacitor_SMD:C... | 0603WAF1103T5E C25805 100mW Thick Film Resistors 75V... | 2 | JLCPCB | Basic | $0.0024

R1,R2,R3,R... | 4K7 | Capacitor_SMD:C... | 0402WGF4701TCE C25900 62.5mW Thick Film Resistors 50... | 22 | JLCPCB | Basic | $0.0110

R6,R20,R23... | 1M | Capacitor_SMD:C... | 0402WGF1004TCE C26083 62.5mW Thick Film Resistors 50... | 10 | JLCPCB | Basic | $0.0050

D4,D5,D10,... | PMEG3050EP | Diode_SMD:D_SOD... | PMEG3050EP,115 C50603 30V 5A 360mV @ 5A SOD128 Schot... | 8 | JLCPCB | Extended | $2.5784

D6,D7,D9 | LED | LED_SMD:LED_060... | 19-217/GHC-YR1S2/3T C72043 20mA 518nm Colorless transpare... | 6 | JLCPCB | Basic | $0.1578

R48 | 17k8 | Capacitor_SMD:C... | RMCF0402FT17K8 C77605 62.5mW Thick Film Resistors 50... | 20 | JLCPCB | Extended | $0.0640

U5 | W25Q16JVS | Package_SO:SOIC... | W25Q16JVSSIQ C82317 SOIC-8_208mil NOR FLASH ROHS | 2 | JLCPCB | Extended | $0.7174

U10,U19 | TPD4EUSB30 | Package_SON:USO... | TPD4EUSB30DQAR C90627 8V 1A (8/20us) 5.5V (Max) 7V U... | 4 | JLCPCB | Extended | $2.1952

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

COMPANY

About JLCPCB (https://jlcpcb.com//aboutUs)

How we work (https://jlcpcb.com//aboutUs/howWorks)

Quality Management (https://jlcpcb.com//aboutUs/qualityControl) (https://jlcpcb.com//aboutUs/qualityControl)

Security (https://jlcpcb.com//aboutUs/security)

CertiIcations (https://jlcpcb.com/help/article/26-CertiIcations) (https://jlcpcb.com/help/article/26-Certifications)

SUPPORT

Help Center (https://jlcpcb.com/help)

Shipping Info (https://jlcpcb.com/help/article/65-Shipping-Methods-and-Delivery-Time) (https://jlcpcb.com/help/article/65-Shipping-Methods-and-Delivery-Time)

How To Order (https://jlcpcb.com/help/catalog/11-How-To-Order) (https://jlcpcb.com/help/catalog/11-How-To-Order)

How To Track (https://jlcpcb.com/help/article/51-How-to-Track-My-Order) (https://jlcpcb.com/help/article/51-How-to-Track-My-Order)

Contact Us (https://jlcpcb.com/help/contact)

Support Team (https://jlcpcb.com//ourTeam)

NETWORK SITES

EasyEDA (https://easyeda.com)

LCSC components (https://lcsc.com/?href=jlc-footer&source=jlc)

(https://www.facebook.com/jlcpcb) | (https://twitter.com/JLCPCB)
(https://www.instagram.com/jlcpcb) | (https://www.youtube.com/JLCPCB)

(https://www.linkedin.com/company/jlcpcb)

CONNECT WITH US

© 2023 JLCPCB.COM All Rights Reserved. Privacy Policy (https://jlcpcb.com/help/article/31-Privacy-Policy) (https://jlcpcb.com/help/article/31-Privacy-Policy) Terms & Conditions (https://jlcpcb.com/help/article/30-Terms-&-Conditions)

< Go back

NNEEXXTT

R41,R45 | 0.01 惟 3W | Resistor_SMD:R_... | 5 | JLCPCB | Extended | $0.2250
U17 | INA219BxD | Package_SO:SOIC... | INA219AIDR C138706 SOIC-8_150mil Current-Sensing... | 2 | JLCPCB | Extended | $2.2656
U8,U9,U12 | TPH3R704PL | PowerIC:TRANS_T... | TPH3R704PL,L1Q C141553 40V 92A 81W 3.7mΩ@10V,46A 2.4V... | 6 | JLCPCB | Extended | $5.1780
CONN1,CONN... | SM04B-SRSS-TB(L... | RP2040:JST_SH4 | SM04B-SRSS-TB(LF)(SN) C160404 1x4P 1 SR/SZ 1mm 4 Copper Allo... | 5 | JLCPCB | Extended | $0.8615
J10 | Micro_SD_Card | Connector_Card:... | 472192001 C164170 Deck Clamshell SMD SD Card Co... | 2 | JLCPCB | Extended | $1.0210
J13 | USB_C_Receptacl... | Connector_USB:U... | TYPE-C-31-M-12 C165948 5A 1 16 Female Type-C SMD USB... | 2 | JLCPCB | Extended | $0.4384
U2 | BMM150 | Package_CSP:WLC... | BMM150 C171681 WLCSP-12 Hall Sensor ROHS | 2 | JLCPCB | Extended | $4.8040
SW1 | CK PCM12SMTR | Button_Switch_S... | PCM12SMTR C221841 SMD Slide Switches ROHS | 2 | JLCPCB | Extended | $0.8462
R46,R47 | 226K | Capacitor_SMD:C... | AC0402FR-07226KL C226354 62.5mW Thick Film Resistors 50... | 20 | JLCPCB | Extended | $0.0240
R29,R54,R6... | 8660 | Capacitor_SMD:C... | AC0402FR-078K66L C227261 62.5mW Thick Film Resistors 50... | 20 | JLCPCB | Extended | $0.0200
Q2,Q3 | DMP3007SCG | Package_SON:Dio... | DMP3007SCG-7 C260899 30V 50A 6.8mΩ@10V,11.5A 2.4W 3... | 4 | JLCPCB | Extended | $2.0176
C1,C2,C3,C... | 100 nF 16V | Capacitor_SMD:C... | CL05B104KB54PNC C307331 50V 100nF X7R ±10% 0402 Multi... | 46 | JLCPCB | Basic | $0.2944
S1,S2 | TS-1187A-B-A-B | PowerIC:SW_TS-1... | TS-1187A-B-A-B C318884 No NO 50mA 5.1mm 100mΩ 100000 ... | 4 | JLCPCB | Basic | $0.0596
R31,R32,R6... | 1180 | Resistor_SMD:R_... | RNCF0402BTE1K18 C346633 62.5mW Thin Film Resistor 50V ... | 9 | JLCPCB | Extended | $0.7263
R53 | 4.7 | Capacitor_SMD:C... | AECR0402F4R70T9 C352412 63mW Thick Film Resistors 50V ... | 20 | JLCPCB | Extended | $0.0360
C41,C42,C4... | 47 uF 25V X7R | Capacitor_SMD:C... | GRM31CR61E476ME44L C403725 25V 47uF X5R ±20% 1206 Multil... | 6 | JLCPCB | Extended | $1.8948
U7,U11,U14... | TVS2200DRV | Package_SON:WSO... | TVS2200DRVR C523793 WSON-6 ESD Protection Devices... | 10 | JLCPCB | Extended | $24.4490
U1 | BMP390L/BMPXXX | PowerIC:XDCR_BM... | BMP388 C779278 LGA-10 Pressure Sensors ROHS | 2 | 1 My Parts 1 JLCPCB | Extended | $2.3729
U13 | MAX77960 | PowerIC:MAX7796... | MAX77960EFV06+ C1020018 FC2QFN-30(4x4) Power Manageme... | 2 | My Parts | Extended | 0
L1 | 3.3 uH DR127-3R... | PowerIC:INDM125... | DR127-3R3-R C2453799 10.5A 3.3uH ±20% 21.5A 5.67mΩ ... | 2 | My Parts | Extended | 0
U3 | BMI160/BMI270 | Package_LGA:Bos... | BMI270 C2836813 LGA-14(2.5x3x0.5mm) Attitude ... | 2 | JLCPCB | Extended | $2.9524
U6 | TPS65987 | PowerIC:TPS6598... | TPS65987DDHRSHR C2868843 VQFN-56 USB ICs ROHS | 2 | JLCPCB | Extended | $10.2764
F1,F2 | Fuse Block | Fuse:Fuseholder... | XF-508P-B C2935468 Plugin Fuse Holders ROHS | 4 | JLCPCB | Extended | $1.2396
U18 | MPM54304-0002 | PowerIC:MPM5430... | MPM54304GMN-0002 C9900037420 Buck Switching Regulator IC Po... | 2 | My Parts | Extended | 0

Please carefully check the packages of selected parts before proceeding.

FMF25FPJR010-LH | C105366
2W 10mΩ ±70ppm/℃ ±1% 2512 Cur...
PCB Prototype & PCB Fabrication Manufacturer - JLCPCB | https://cart.jlcpcb.com/smtQuote?pcbFileNo=1eeebdad9bf540228a708...
2 of 2 | 1/6/23, 10:03 AM

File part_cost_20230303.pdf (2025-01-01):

PCB Prototype & PCB Fabrication Manufacturer - JLCPCB | https://cart.jlcpcb.com/smt-order/?pcbFileNo=84745c5698fa448380df...

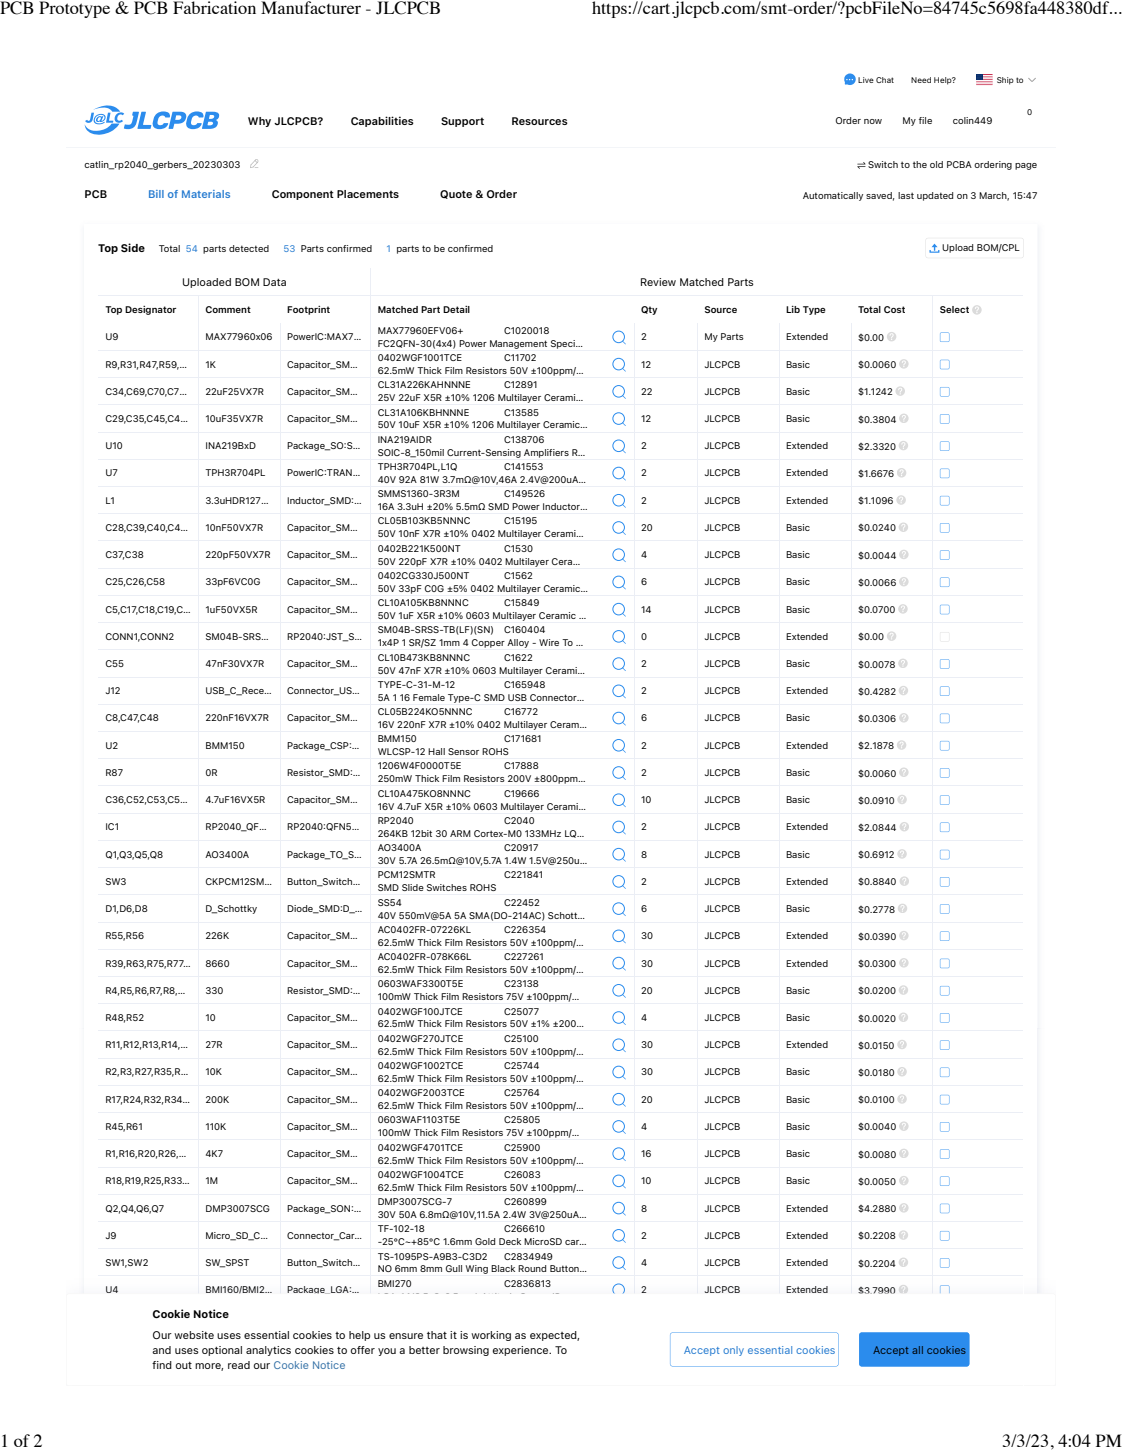
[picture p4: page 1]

Automatically saved, last updated on 3 March, 15:47

Uploaded BOM Data | Review Matched Parts

Top Designator | Comment | Footprint | Matched Part Detail | Qty | Source | Lib Type | Total Cost | Select
U9 | MAX77960x06 | PowerIC:MAX7… | MAX77960EFV06+ C1020018 FC2QFN-30(4x4) Power Management Speci… | 2 | My Parts | Extended | $0.00

R9,R31,R47,R59,… | 1K | Capacitor_SM… | 0402WGF1001TCE C11702 62.5mW Thick Film Resistors 50V ±100ppm/… | 12 | JLCPCB | Basic | $0.0060

C34,C69,C70,C7… | 22uF25VX7R | Capacitor_SM… | CL31A226KAHNNNE C12891 25V 22uF X5R ±10% 1206 Multilayer Cerami… | 22 | JLCPCB | Basic | $1.1242

C29,C35,C45,C4… | 10uF35VX7R | Capacitor_SM… | CL31A106KBHNNNE C13585 50V 10uF X5R ±10% 1206 Multilayer Ceramic… | 12 | JLCPCB | Basic | $0.3804

U10 | INA219BxD | Package_SO:S… | INA219AIDR C138706 SOIC-8_150mil Current-Sensing Amplifiers R… | 2 | JLCPCB | Extended | $2.3320

U7 | TPH3R704PL | PowerIC:TRAN… | TPH3R704PL,L1Q C141553 40V 92A 81W 3.7mΩ@10V,46A 2.4V@200uA… | 2 | JLCPCB | Extended | $1.6676

L1 | 3.3uHDR127… | Inductor_SMD:… | SMMS1360-3R3M C149526 16A 3.3uH ±20% 5.5mΩ SMD Power Inductor… | 2 | JLCPCB | Extended | $1.1096

C28,C39,C40,C4… | 10nF50VX7R | Capacitor_SM… | CL05B103KB5NNNC C15195 50V 10nF X7R ±10% 0402 Multilayer Cerami… | 20 | JLCPCB | Basic | $0.0240

C37,C38 | 220pF50VX7R | Capacitor_SM… | 0402B221K500NT C1530 50V 220pF X7R ±10% 0402 Multilayer Cera… | 4 | JLCPCB | Basic | $0.0044

C25,C26,C58 | 33pF6VC0G | Capacitor_SM… | 0402CG330J500NT C1562 50V 33pF C0G ±5% 0402 Multilayer Ceramic… | 6 | JLCPCB | Basic | $0.0066

C5,C17,C18,C19,C… | 1uF50VX5R | Capacitor_SM… | CL10A105KB8NNNC C15849 50V 1uF X5R ±10% 0603 Multilayer Ceramic … | 14 | JLCPCB | Basic | $0.0700

CONN1,CONN2 | SM04B-SRS… | RP2040:JST_S… | SM04B-SRSS-TB(LF)(SN) C160404 1x4P 1 SR/SZ 1mm 4 Copper Alloy - Wire To … | 0 | JLCPCB | Extended | $0.00

C55 | 47nF30VX7R | Capacitor_SM… | CL10B473KB8NNNC C1622 50V 47nF X7R ±10% 0603 Multilayer Cerami… | 2 | JLCPCB | Basic | $0.0078

J12 | USB_C_Rece… | Connector_US… | TYPE-C-31-M-12 C165948 5A 1 16 Female Type-C SMD USB Connector… | 2 | JLCPCB | Extended | $0.4282

C8,C47,C48 | 220nF16VX7R | Capacitor_SM… | CL05B224KO5NNNC C16772 16V 220nF X7R ±10% 0402 Multilayer Ceram… | 6 | JLCPCB | Basic | $0.0306

U2 | BMM150 | Package_CSP:… | BMM150 C171681 WLCSP-12 Hall Sensor ROHS | 2 | JLCPCB | Extended | $2.1878

R87 | 0R | Resistor_SMD:… | 1206W4F0000T5E C17888 250mW Thick Film Resistors 200V ±800ppm… | 2 | JLCPCB | Basic | $0.0060

C36,C52,C53,C5… | 4.7uF16VX5R | Capacitor_SM… | CL10A475KO8NNNC C19666 16V 4.7uF X5R ±10% 0603 Multilayer Cerami… | 10 | JLCPCB | Basic | $0.0910

IC1 | RP2040_QF… | RP2040:QFN5… | RP2040 C2040 264KB 12bit 30 ARM Cortex-M0 133MHz LQ… | 2 | JLCPCB | Extended | $2.0844

Q1,Q3,Q5,Q8 | AO3400A | Package_TO_S… | AO3400A C20917 30V 5.7A 26.5mΩ@10V,5.7A 1.4W 1.5V@250u… | 8 | JLCPCB | Basic | $0.6912

SW3 | CKPCM12SM… | Button_Switch… | PCM12SMTR C221841 SMD Slide Switches ROHS | 2 | JLCPCB | Extended | $0.8840

D1,D6,D8 | D_Schottky | Diode_SMD:D_… | SS54 C22452 40V 550mV@5A 5A SMA(DO-214AC) Schott… | 6 | JLCPCB | Basic | $0.2778

R55,R56 | 226K | Capacitor_SM… | AC0402FR-07226KL C226354 62.5mW Thick Film Resistors 50V ±100ppm/… | 30 | JLCPCB | Extended | $0.0390

R39,R63,R75,R77… | 8660 | Capacitor_SM… | AC0402FR-078K66L C227261 62.5mW Thick Film Resistors 50V ±100ppm/… | 30 | JLCPCB | Extended | $0.0300

R4,R5,R6,R7,R8,… | 330 | Resistor_SMD:… | 0603WAF3300T5E C23138 100mW Thick Film Resistors 75V ±100ppm/… | 20 | JLCPCB | Basic | $0.0200

R48,R52 | 10 | Capacitor_SM… | 0402WGF100JTCE C25077 62.5mW Thick Film Resistors 50V ±1% ±200… | 4 | JLCPCB | Basic | $0.0020

R11,R12,R13,R14,… | 27R | Capacitor_SM… | 0402WGF270JTCE C25100 62.5mW Thick Film Resistors 50V ±100ppm/… | 30 | JLCPCB | Extended | $0.0150

R2,R3,R27,R35,R… | 10K | Capacitor_SM… | 0402WGF1002TCE C25744 62.5mW Thick Film Resistors 50V ±100ppm/… | 30 | JLCPCB | Basic | $0.0180

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

PCB Prototype & PCB Fabrication Manufacturer - JLCPCB | https://cart.jlcpcb.com/smt-order/?pcbFileNo=84745c5698fa448380df...

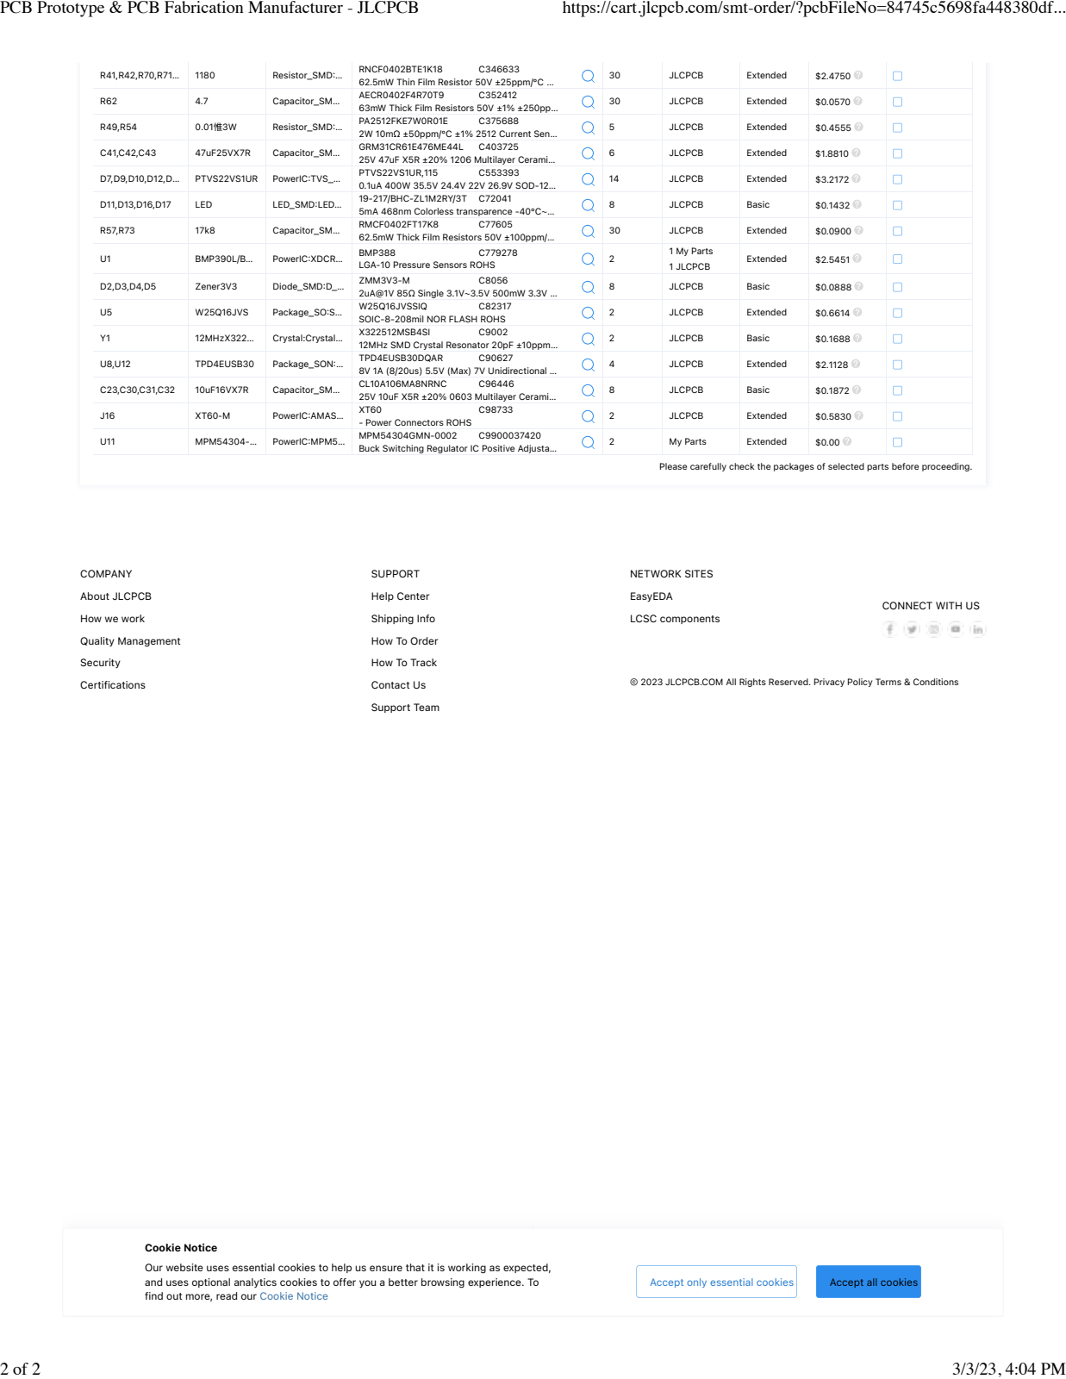
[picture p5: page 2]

COMPANY

About JLCPCB (https://cart.jlcpcb.com/aboutUs)

How we work (https://cart.jlcpcb.com/aboutUs/howWorks)

Quality Management (https://cart.jlcpcb.com/aboutUs/qualityControl)

Security (https://cart.jlcpcb.com/aboutUs/security)

Certifications (https://support.jlcpcb.com/article/64-certifications)

SUPPORT

Help Center (https://support.jlcpcb.com/)

Shipping Info (https://support.jlcpcb.com/article/27-shipping-methods-and-delivery-time)

How To Order (https://support.jlcpcb.com/article/21-how-do-i-place-an-order)

How To Track (https://support.jlcpcb.com/article/141-how-to-track-my-order)

Contact Us (https://support.jlcpcb.com/article/45-contact-jlcpcb)

Support Team (https://cart.jlcpcb.com/ourTeam)

NETWORK SITES

EasyEDA (https://easyeda.com/)

LCSC components (https://lcsc.com/?href=jlc-footer&source=jlc)

CONNECT WITH US

© 2023 JLCPCB.COM All Rights Reserved. Privacy Policy (https://jlcpcb.com/help/article/31-Privacy-Policy) Terms & Conditions (https://jlcpcb.com/help/article/30-Terms-&-Conditions)

Please carefully check the packages of selected parts before proceeding.

R41,R42,R70,R71… | 1180 | Resistor_SMD:… | RNCF0402BTE1K18 | C346633
62.5mW Thin Film Resistor 50V ±25ppm/℃ … | 30 | JLCPCB | Extended | $2.4750
R62 | 4.7 | Capacitor_SM… | AECR0402F4R70T9 C352412 63mW Thick Film Resistors 50V ±1% ±250pp… | 30 | JLCPCB | Extended | $0.0570
R49,R54 | 0.01惟3W | Resistor_SMD:… | PA2512FKE7W0R01E C375688 2W 10mΩ ±50ppm/℃ ±1% 2512 Current Sen… | 5 | JLCPCB | Extended | $0.4555
C41,C42,C43 | 47uF25VX7R | Capacitor_SM… | GRM31CR61E476ME44L C403725 25V 47uF X5R ±20% 1206 Multilayer Cerami… | 6 | JLCPCB | Extended | $1.8810
D7,D9,D10,D12,D… | PTVS22VS1UR | PowerIC:TVS_… | PTVS22VS1UR,115 C553393 0.1uA 400W 35.5V 24.4V 22V 26.9V SOD-12… | 14 | JLCPCB | Extended | $3.2172
D11,D13,D16,D17 | LED | LED_SMD:LED… | 19-217/BHC-ZL1M2RY/3T C72041 5mA 468nm Colorless transparence -40℃~… | 8 | JLCPCB | Basic | $0.1432
R57,R73 | 17k8 | Capacitor_SM… | RMCF0402FT17K8 C77605 62.5mW Thick Film Resistors 50V ±100ppm/… | 30 | JLCPCB | Extended | $0.0900
U1 | BMP390L/B… | PowerIC:XDCR… | BMP388 LGA-10 Pressure Sensors ROHS C779278 | 2 | 1 My Parts 1 JLCPCB | Extended | $2.5451
D2,D3,D4,D5 | Zener3V3 | Diode_SMD:D_… | ZMM3V3-M C8056 2uA@1V 85Ω Single 3.1V~3.5V 500mW 3.3V … | 8 | JLCPCB | Basic | $0.0888
U5 | W25Q16JVS | Package_SO:S… | W25Q16JVSSIQ C82317 SOIC-8-208mil NOR FLASH ROHS | 2 | JLCPCB | Extended | $0.6614
Y1 | 12MHzX322… | Crystal:Crystal… | X322512MSB4SI C9002 12MHz SMD Crystal Resonator 20pF ±10ppm… | 2 | JLCPCB | Basic | $0.1688
U8,U12 | TPD4EUSB30 | Package_SON:… | TPD4EUSB30DQAR C90627 8V 1A (8/20us) 5.5V (Max) 7V Unidirectional … | 4 | JLCPCB | Extended | $2.1128
C23,C30,C31,C32 | 10uF16VX7R | Capacitor_SM… | CL10A106MA8NRNC C96446 25V 10uF X5R ±20% 0603 Multilayer Cerami… | 8 | JLCPCB | Basic | $0.1872
J16 | XT60-M | PowerIC:AMAS… | XT60 C98733 - Power Connectors ROHS | 2 | JLCPCB | Extended | $0.5830
U11 | MPM54304-… | PowerIC:MPM5… | MPM54304GMN-0002 C9900037420 Buck Switching Regulator IC Positive Adjusta… | 2 | My Parts | Extended | $0.00

Cookie Notice
Our website uses essential cookies to help us ensure that it is working as expected, and uses optional analytics cookies to offer you a better browsing experience. To find out more, read our Cookie Notice (https://jlcpcb.com/help/article/133-JLCPCB-Cookie-Notice)
Accept only essential cookies | Accept all cookies
2 of 2 | 3/3/23, 4:04 PM

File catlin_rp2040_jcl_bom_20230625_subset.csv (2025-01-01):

Designator | Comment | Footprint | JCLPCB Part #
C1, C2, C3, C4, C5, C6, C8, C9, C10, C11, C12, C13, C14, C15, C16, C20, C21, C22, C24, C39, C57, C59, C60, C65, C80, C81, | 100 nF 25V X7R | Capacitor_SMD:C_0402_1005Metric | C307331
C7, C17, C18, C19, C27, C31, C33, C73, C79, C82, | 1 uF 50V X5R | Capacitor_SMD:C_0603_1608Metric | C15849
C23, | 10 uF 16V X7R | Capacitor_SMD:C_0603_1608Metric_Pad1.08x0.95mm_HandSolder | C96446
C25, C26, C52, | 33 pF 6V C0G | Capacitor_SMD:C_0402_1005Metric_Pad0.74x0.62mm_HandSolder | C1562
C28, C32, C34, C35, C44, C45, C53, C61, C62, C70, C74, C75, | 10 nF 50V X7R | Capacitor_SMD:C_0402_1005Metric_Pad0.74x0.62mm_HandSolder | C15195
C29, C30, | 220 pF 50V X7R | Capacitor_SMD:C_0402_1005Metric_Pad0.74x0.62mm_HandSolder | C1530
C36, C37, C38, | 47 uF 25V X7R | Capacitor_SMD:C_1210_3225Metric | C403725
C40, C41, C46, C49, | 10 uF 35V X7R | Capacitor_SMD:C_1206_3216Metric | C13585
C42, C43, | 220 nF 16V X7R | Capacitor_SMD:C_0402_1005Metric | C16772
C47, C48, C51, C78, | 4.7 uF 16V X5R | Capacitor_SMD:C_0603_1608Metric_Pad1.08x0.95mm_HandSolder | C19666
C50, | 47 nF 30V X7R | Capacitor_SMD:C_0603_1608Metric_Pad1.08x0.95mm_HandSolder | C1622
C63, C64, C66, C67, C68, C69, C71, C72, C76, C77, | 22 uF 25V X7R | Capacitor_SMD:C_1210_3225Metric_Pad1.33x2.70mm_HandSolder | C12891
CONN1, CONN2, | SM04B-SRSS-TB(LF)(SN) | RP2040:JST_SH4 | C160404
D1, D7, D17, | D_Schottky | Diode_SMD:D_SMA | C22452
D2, D3, D4, | Zener 3V3 | Diode_SMD:D_MiniMELF | C545375
D5, D9, D11, D13, D18, D19, | PTVS22VS1UR | PowerIC:TVS_PTVS22VS1UR | C553393
D10, D12, | LED_GREEN | LED_SMD:LED_0603_1608Metric | C72043
D15, D16, D20, D21, | LED_BLUE | LED_SMD:LED_0603_1608Metric | C72041
F1, | Fuse Holder | Fuse:Fuseholder_Blade_Mini_Keystone_3568 | C2935468
IC1, | RP2040_QFN56 | RP2040:QFN56_7MM_REDUCEDEPAD | C2040
IC2, | CYPD3177-24LQXQ | PowerIC:QFN50P400X400X60-25N-D | C2959321
J12, | Micro_SD_Card | Connector_Card:microSD_HC_Molex_47219-2001 | C266610
J15, | USB_C_Receptacle_USB2.0 | Connector_USB:USB_C_Receptacle_HRO_TYPE-C-31-M-12 | C165948
J20, | XT60-M | PowerIC:AMASS_XT60-M | C98733
L1, | 3.3 uH DR127-3R3-R | Inductor_SMD:InductorSMMS1360 | C149526
Q1, Q3, Q5, Q9, Q10, | BSS138 | Package_TO_SOT_SMD:SOT-23 | C400505
Q2, Q4, Q6, Q7, Q8, | DMP3007SCG | Package_SON:Diodes_PowerDI3333-8 | C5242075
R1, R2, R3, R4, R5, R6, R16, R34, R45, R49, R50, R52, R57, R59, R72, R74, R79, R81, R88, R92, R93, | 10K | Capacitor_SMD:C_0402_1005Metric_Pad0.74x0.62mm_HandSolder | C25744
R7, R8, R9, R10, R11, R17, R20, R25, R28, R29, | 330 | Resistor_SMD:R_0603_1608Metric | C23138
R12, R38, R46, R63, R64, R69, | 1K | Capacitor_SMD:C_0402_1005Metric_Pad0.74x0.62mm_HandSolder | C11702
R13, R40, R65, R67, R86, | 200K | Capacitor_SMD:C_0402_1005Metric_Pad0.74x0.62mm_HandSolder | C25764
R14, R15, R18, R19, R22, R30, R36, R37, | 27R | Capacitor_SMD:C_0402_1005Metric_Pad0.74x0.62mm_HandSolder | C25100
R21, R26, R33, R35, R58, R82, R98, R100, | 4K7 | Resistor_SMD:R_0603_1608Metric_Pad0.98x0.95mm_HandSolder | C23162
R23, R31, R32, R44, R60, R96, R99, | 110K | Capacitor_SMD:C_0603_1608Metric | C25805
R24, R27, R39, R42, R43, R68, | 1M | Capacitor_SMD:C_0402_1005Metric_Pad0.74x0.62mm_HandSolder | C26083
R47, R51, R70, R71, | 10 | Capacitor_SMD:C_0402_1005Metric_Pad0.74x0.62mm_HandSolder | C25077
R48, R53, | 0.01 Ω 3W | Resistor_SMD:R_2512_6332Metric | C500740
R54, R55, | 226K | Capacitor_SMD:C_0402_1005Metric_Pad0.74x0.62mm_HandSolder | C226354
R56, R66, R73, R89, R97, | 17k8 | Capacitor_SMD:C_0402_1005Metric_Pad0.74x0.62mm_HandSolder | C77605
R61, | 4.7 | Capacitor_SMD:C_0603_1608Metric | C23164
R62, R75, R77, R83, R84, R85, | 8660 | Capacitor_SMD:C_0402_1005Metric_Pad0.74x0.62mm_HandSolder | C2684545
R76, R78, R80, | 1180 | Resistor_SMD:R_0402_1005Metric_Pad0.72x0.64mm_HandSolder | C346633
R87, R91, R94, | 0R | Resistor_SMD:R_1206_3216Metric | C17888
SW1, SW2, SW3, | SW_SPST | Button_Switch_SMD:SW_Push_1P1T_NO_6x6mm_H9.5mm | C2834949
SW4, | CK PCM12SMTR | Button_Switch_SMD:SW_SPDT_PCM12 | C128955
U1, | LSM6DSOXTR | PowerIC:PQFN50P250X300X86-14N | C2655100
U2, | BMP390L/BMPxxx | PowerIC:XDCR_BMP390L | C779278
U3, | PCF8523T | Package_SO:SOIC-8_3.9x4.9mm_P1.27mm | C2651516
U5, | LIS3MDLTR | PowerIC:LIS3MDLTR | C478483
U6, | W25Q16JVS | Package_SO:SOIC-8_5.23x5.23mm_P1.27mm | C82317
U7, U9, U13, | TPD4EUSB30 | Package_SON:USON-10_2.5x1.0mm_P0.5mm | C558427
U8, | TPH3R704PL | PowerIC:TRANS_TPHR8504PL,L1Q | C141553
U10, | MAX77960x06 | PowerIC:MAX77961EFV06 | C1020018
U11, | INA219BxD | Package_SO:SOIC-8_3.9x4.9mm_P1.27mm | C138706
U12, | MPM54304-0002 | PowerIC:MPM54304GMN-0002 | C9900037420
Y1, | 32.768 kHz | Crystal:Crystal_SMD_3215-2Pin_3.2x1.5mm | C32346
Y2, | 12MHz X322512MSB4SI | Crystal:Crystal_SMD_3225-4Pin_3.2x2.5mm | C9002

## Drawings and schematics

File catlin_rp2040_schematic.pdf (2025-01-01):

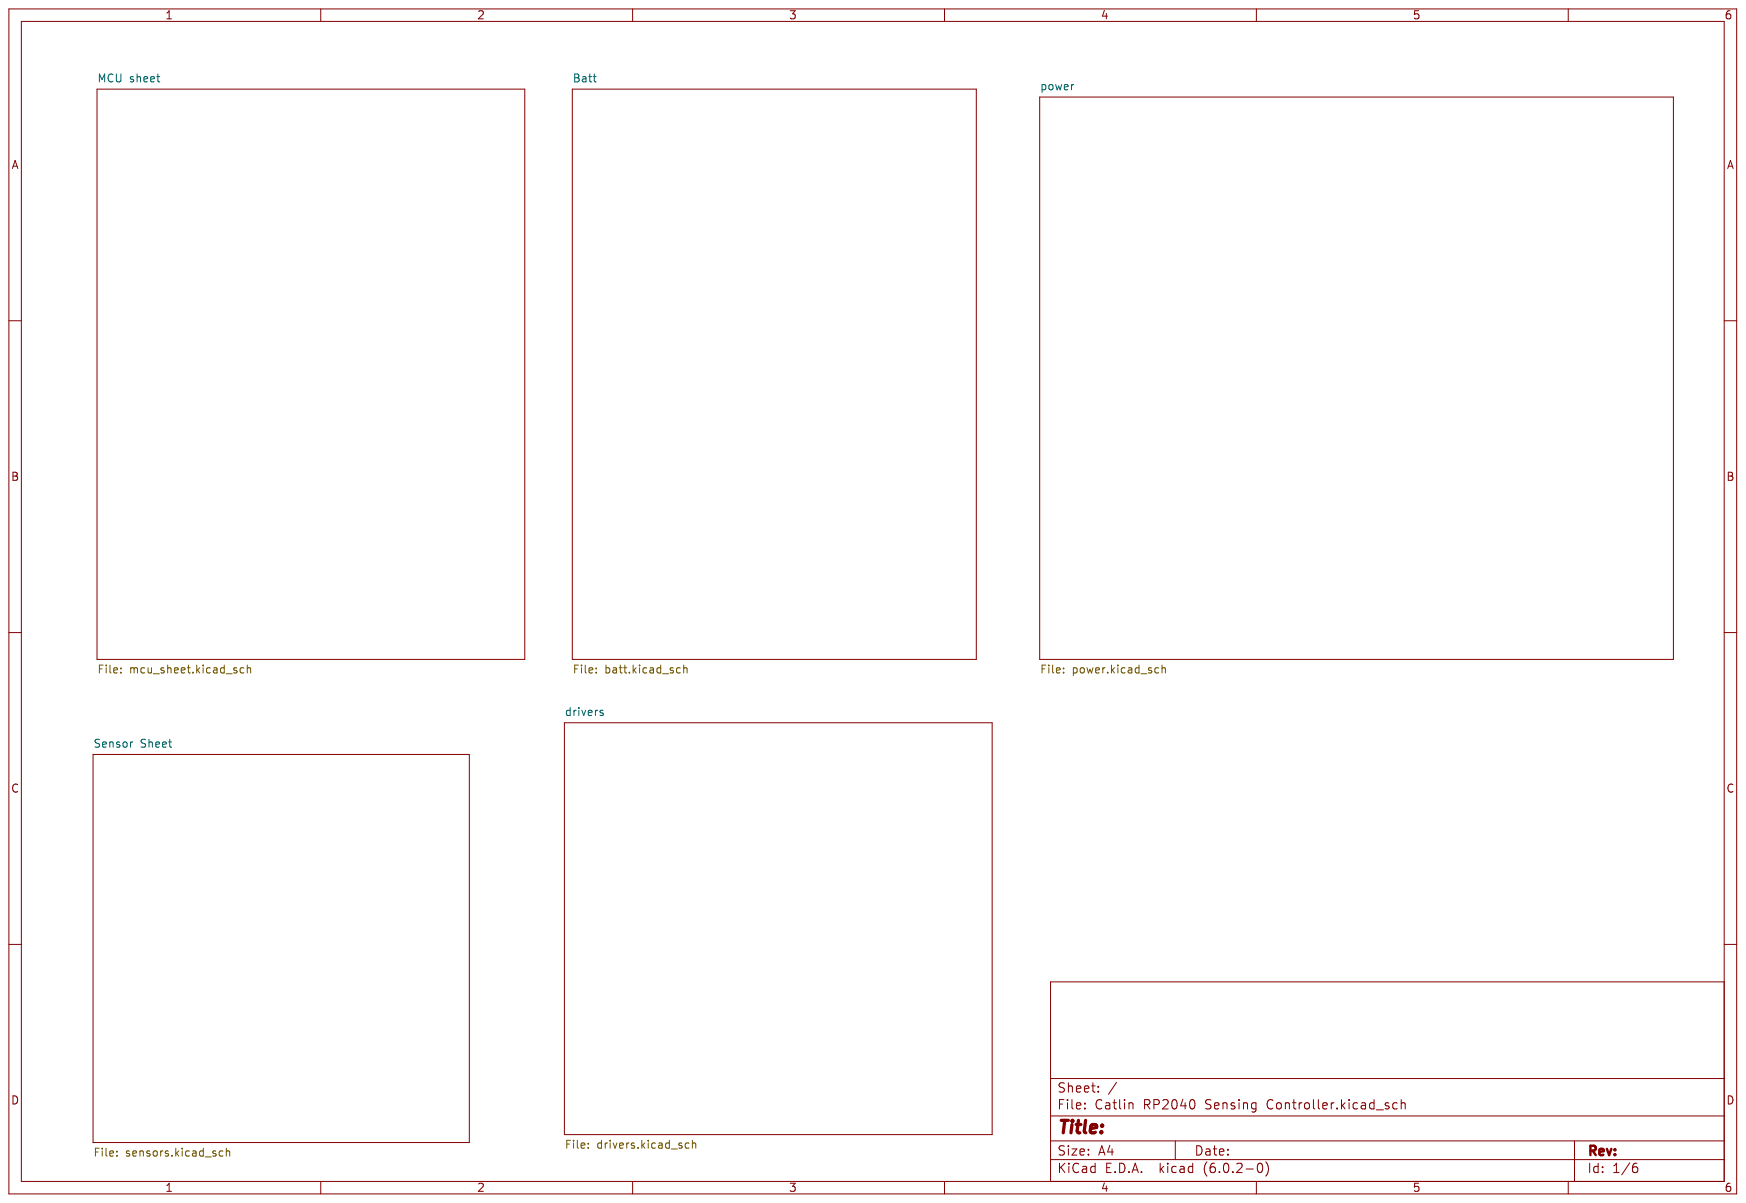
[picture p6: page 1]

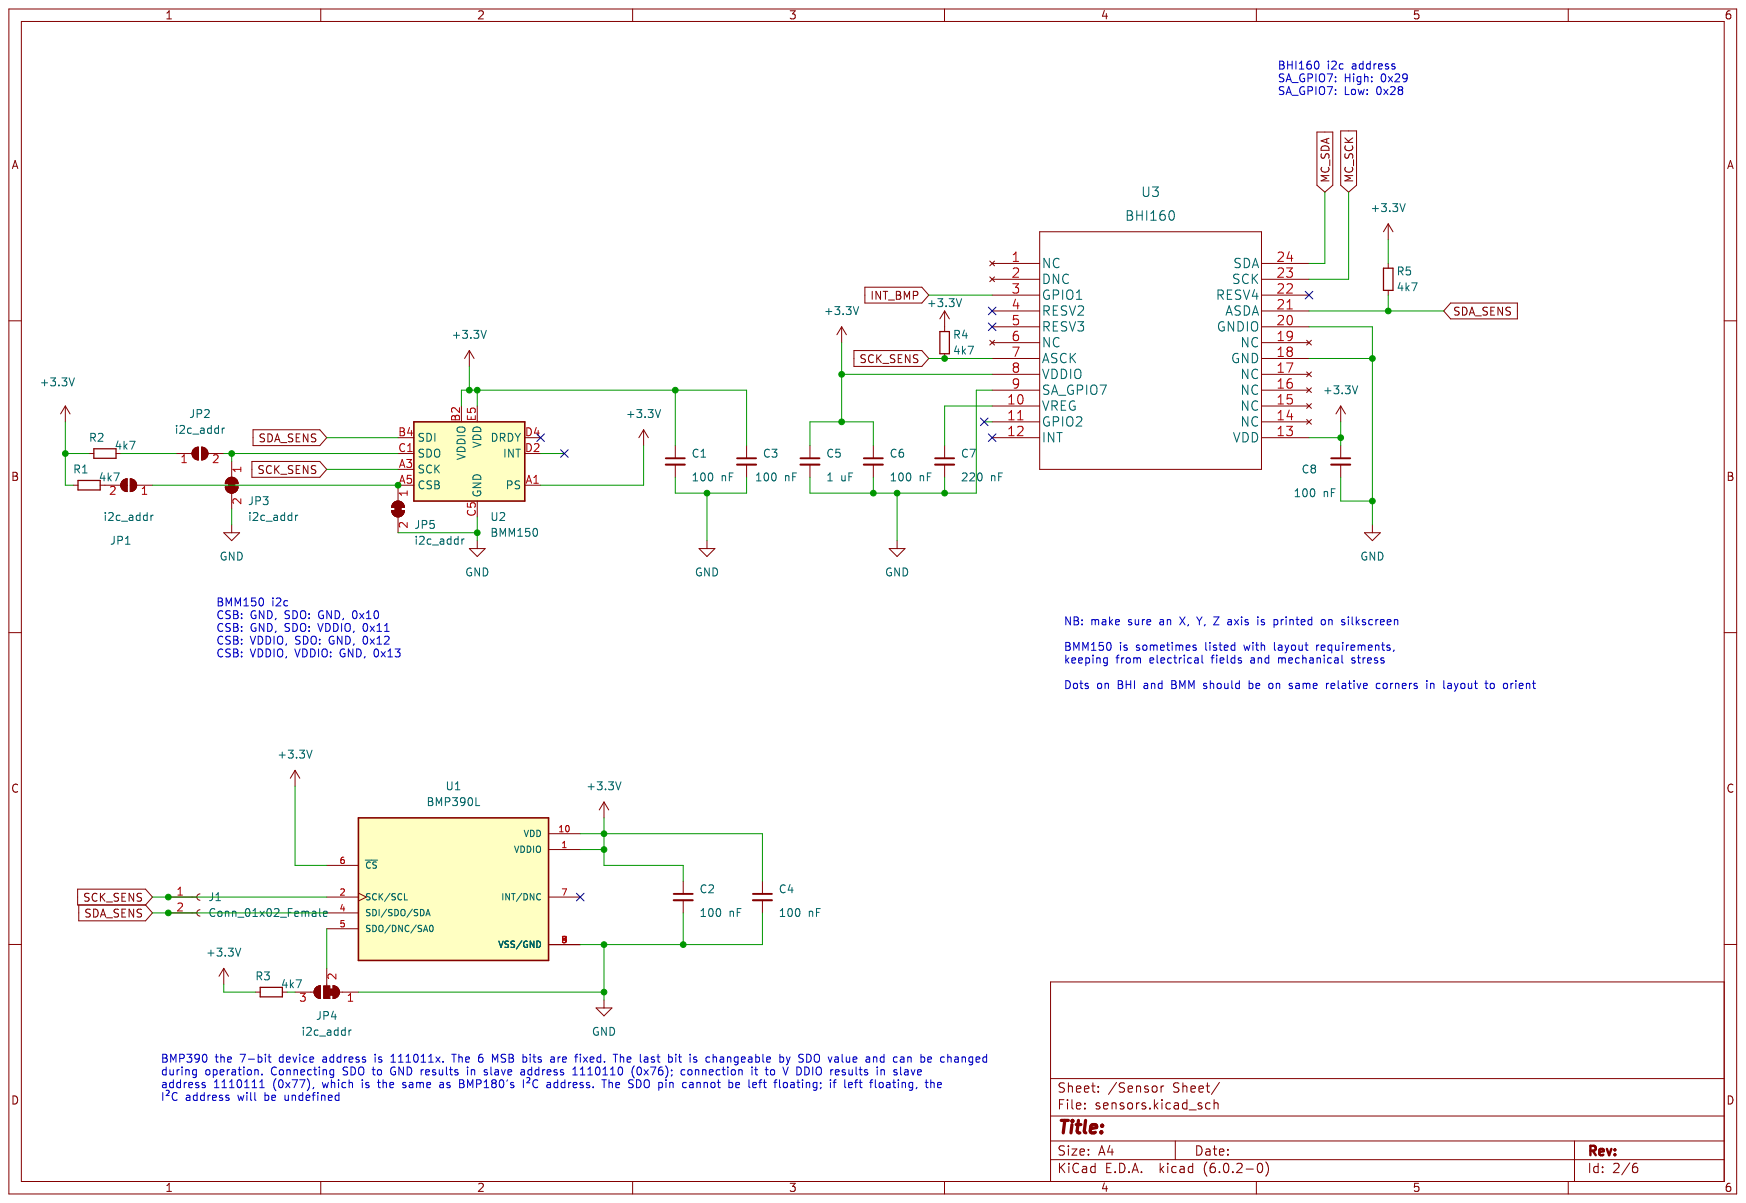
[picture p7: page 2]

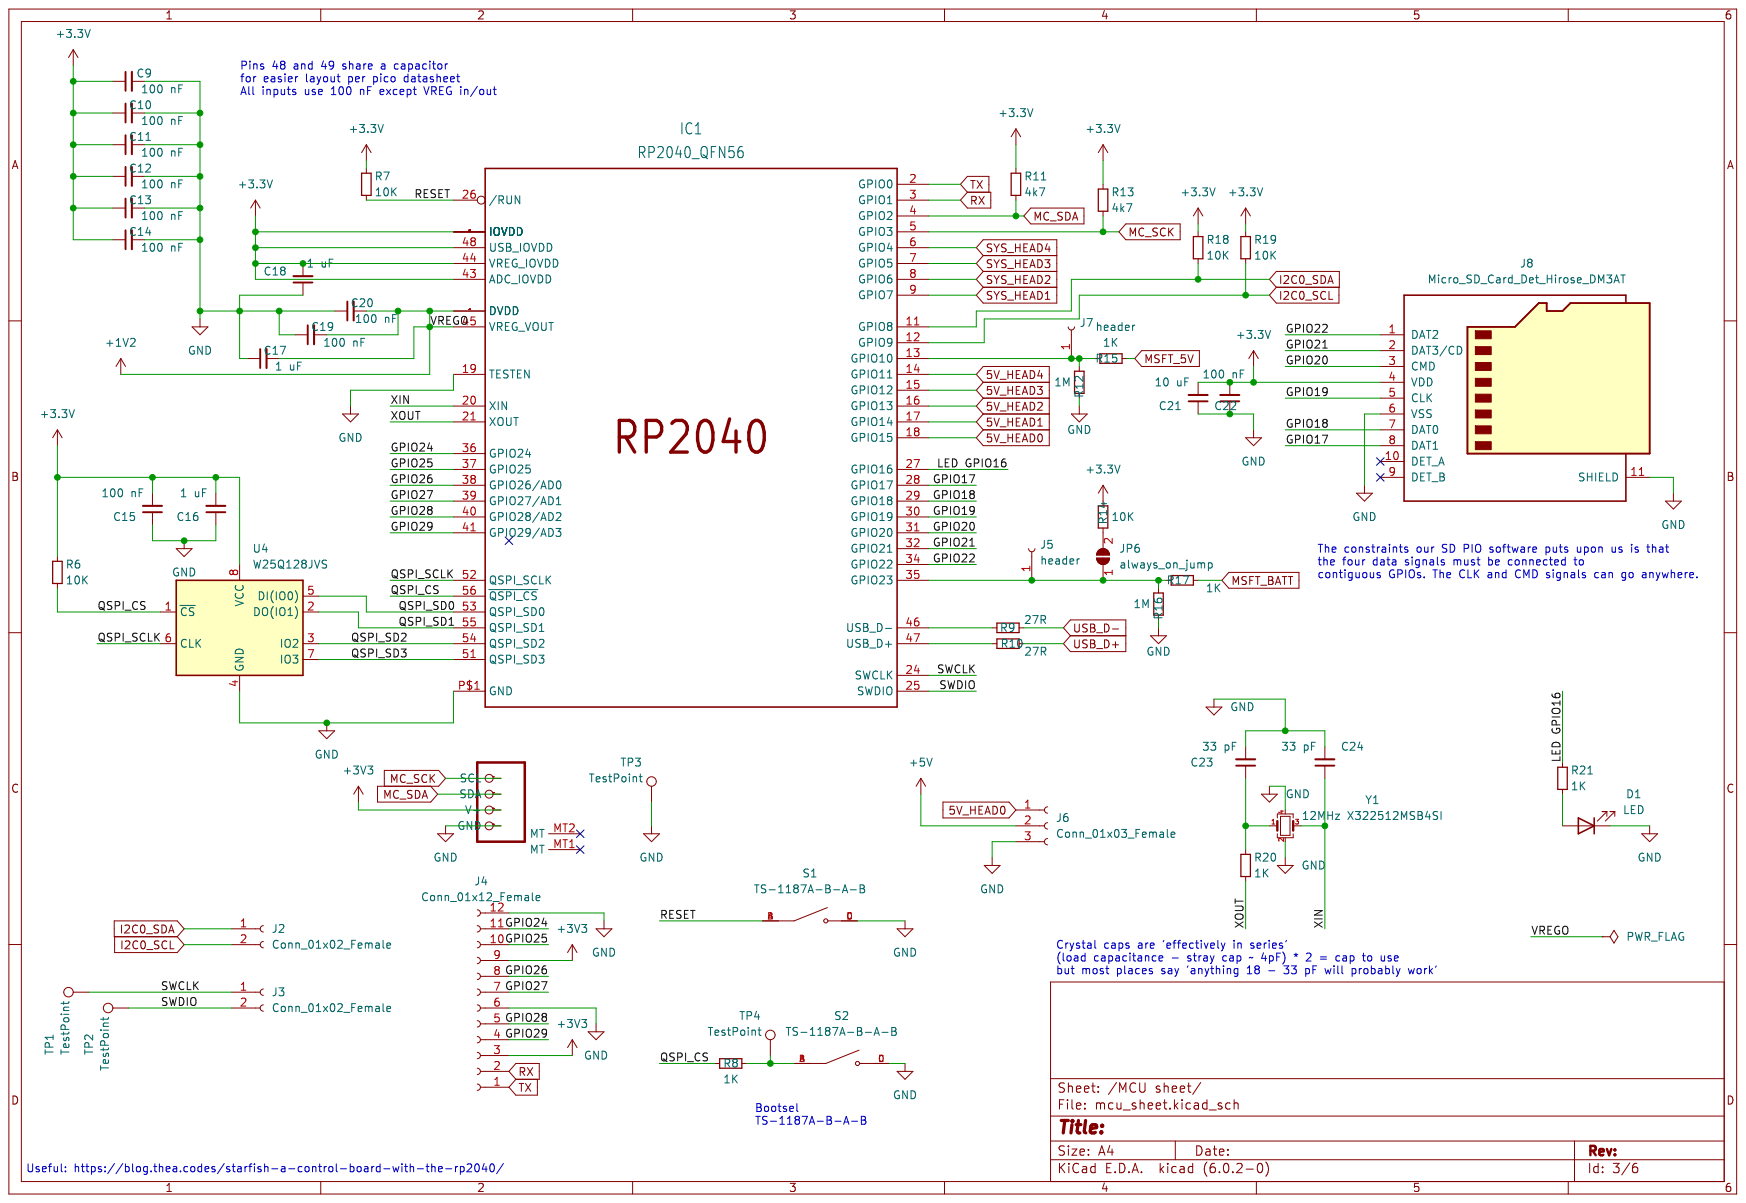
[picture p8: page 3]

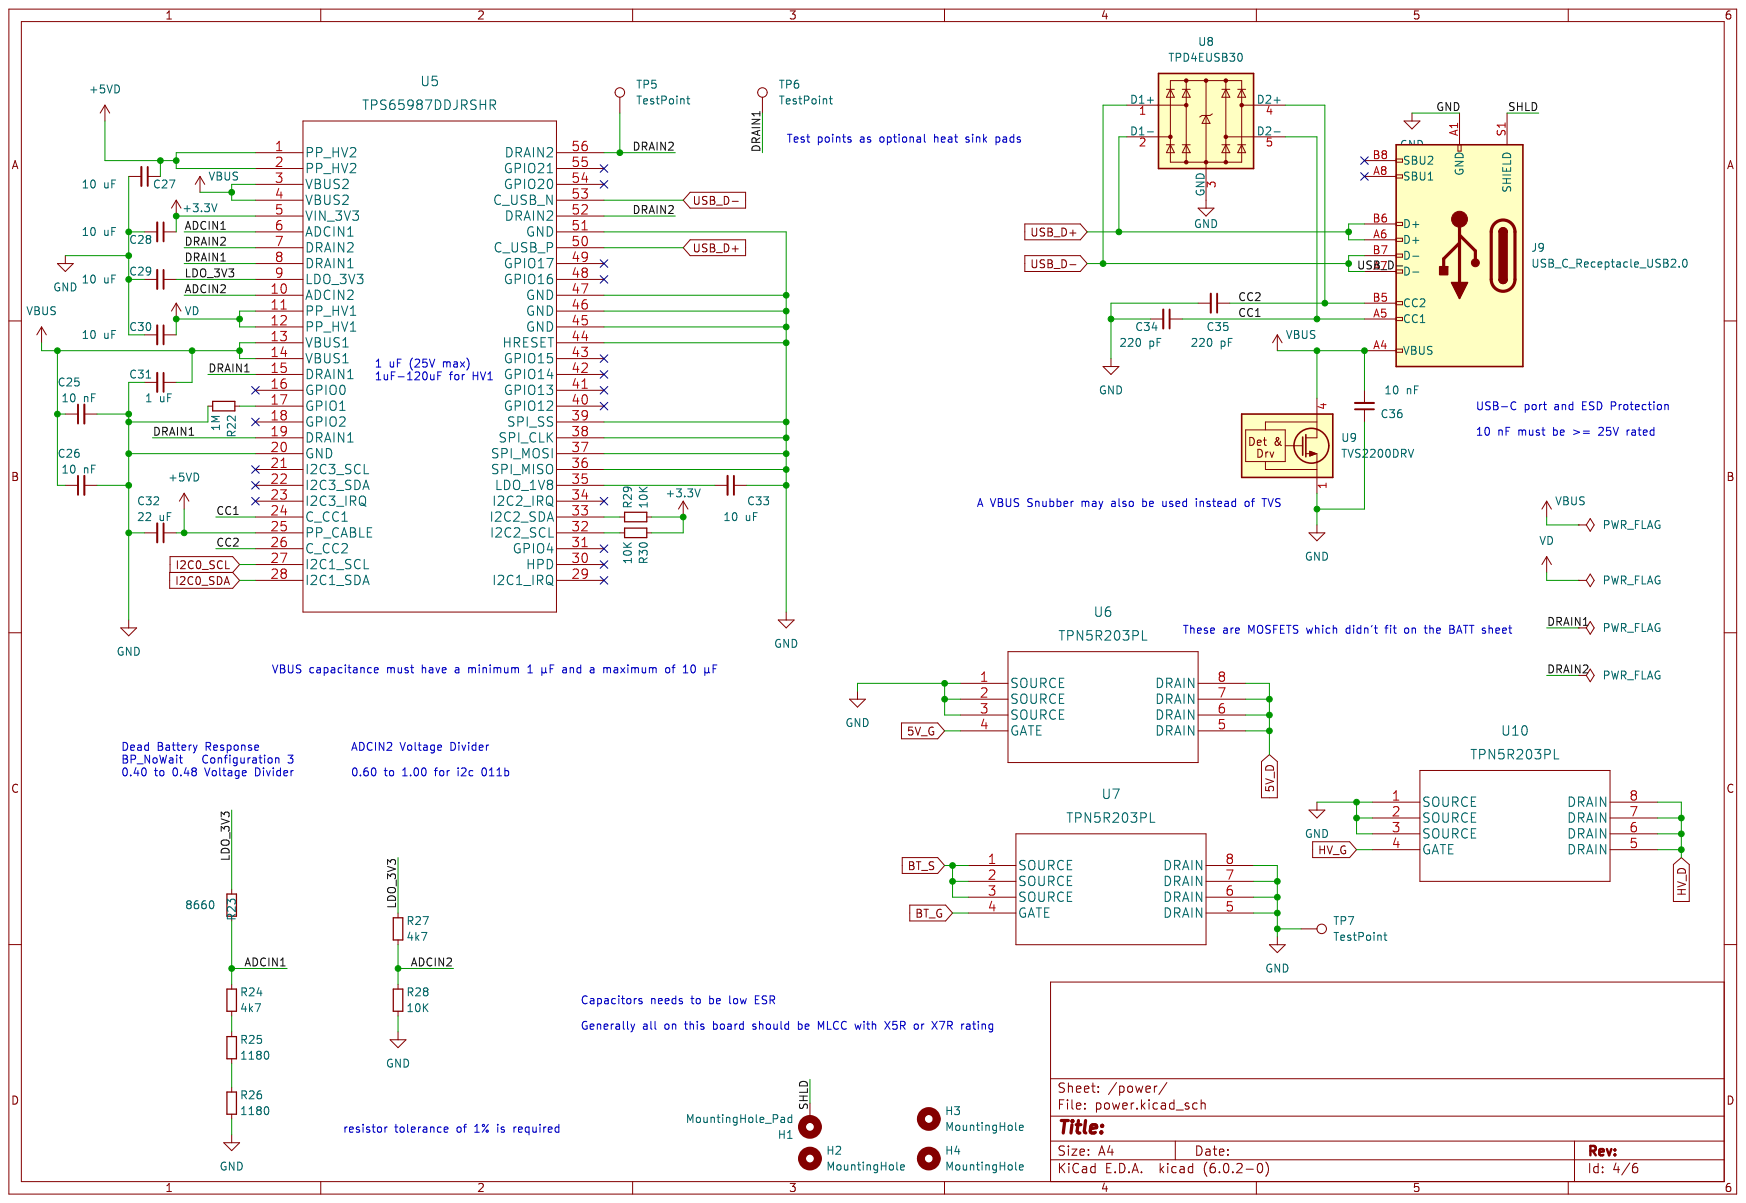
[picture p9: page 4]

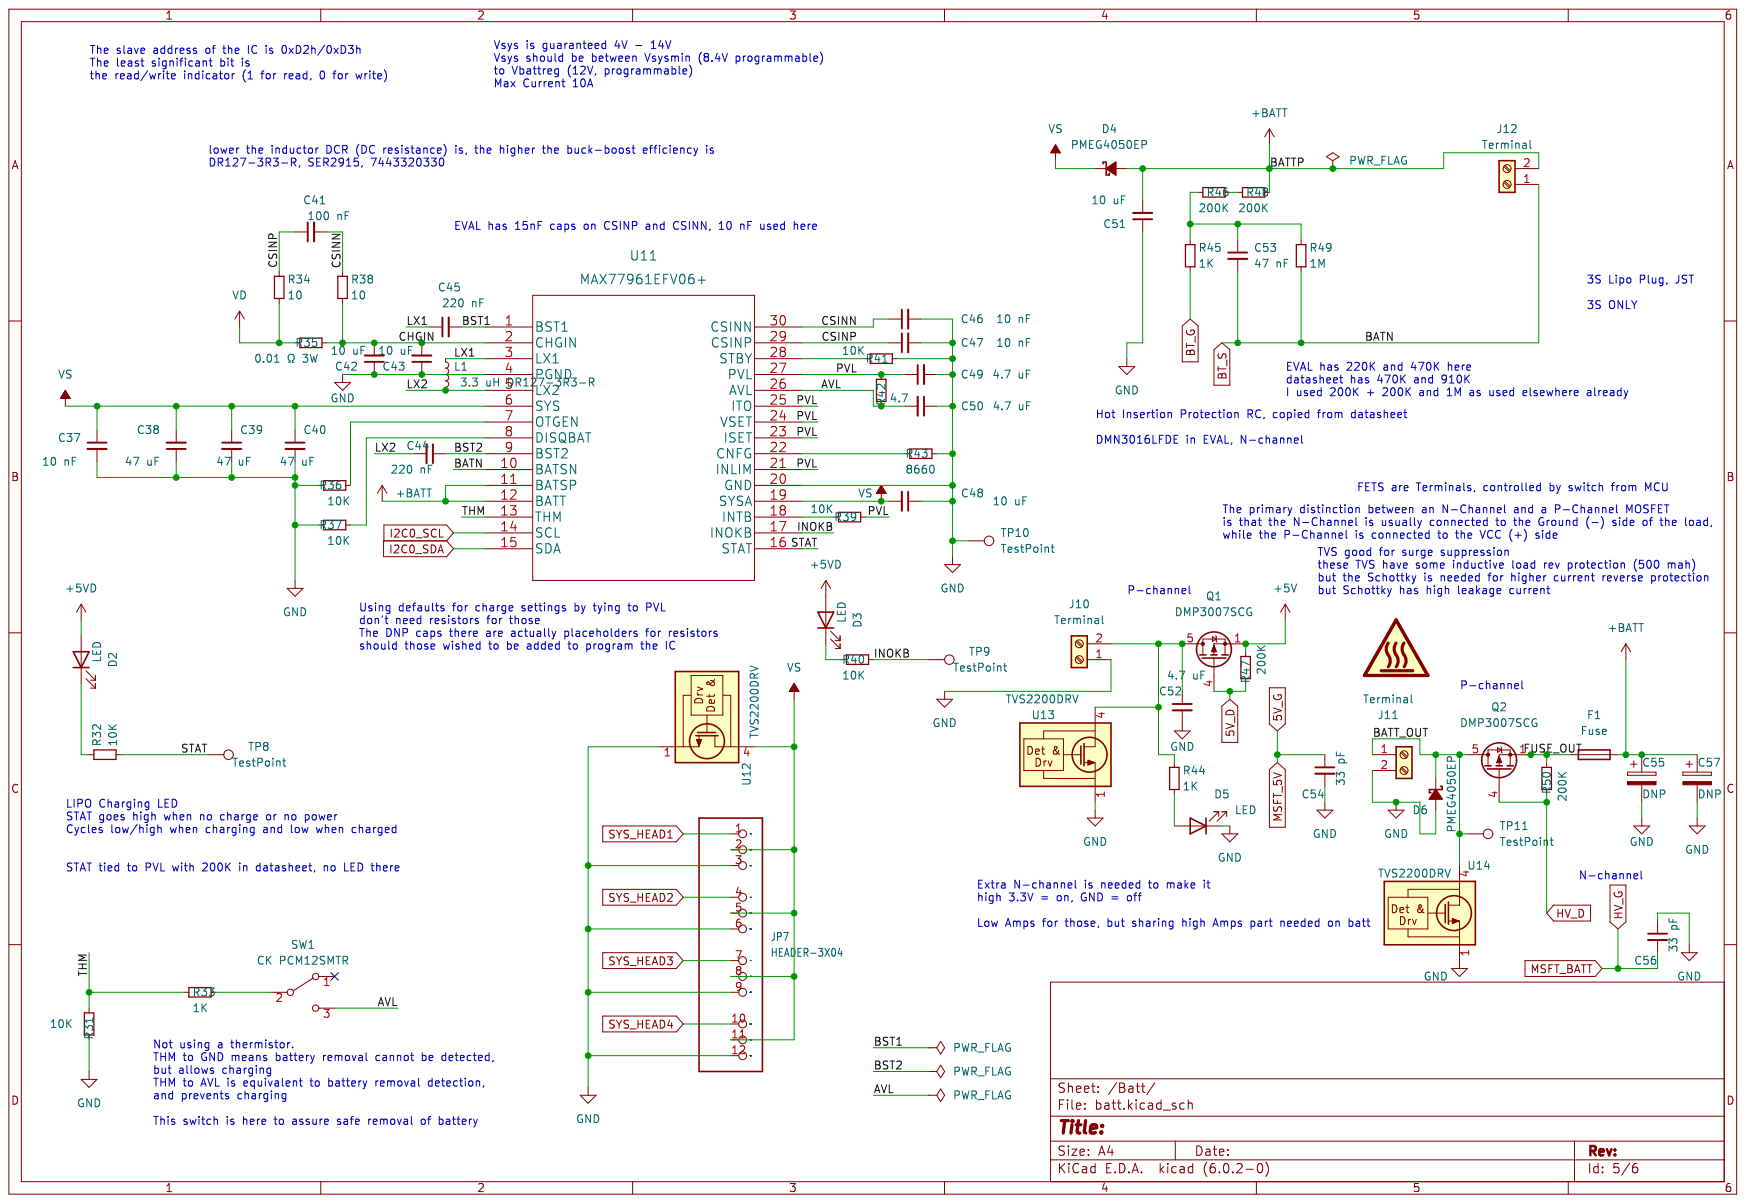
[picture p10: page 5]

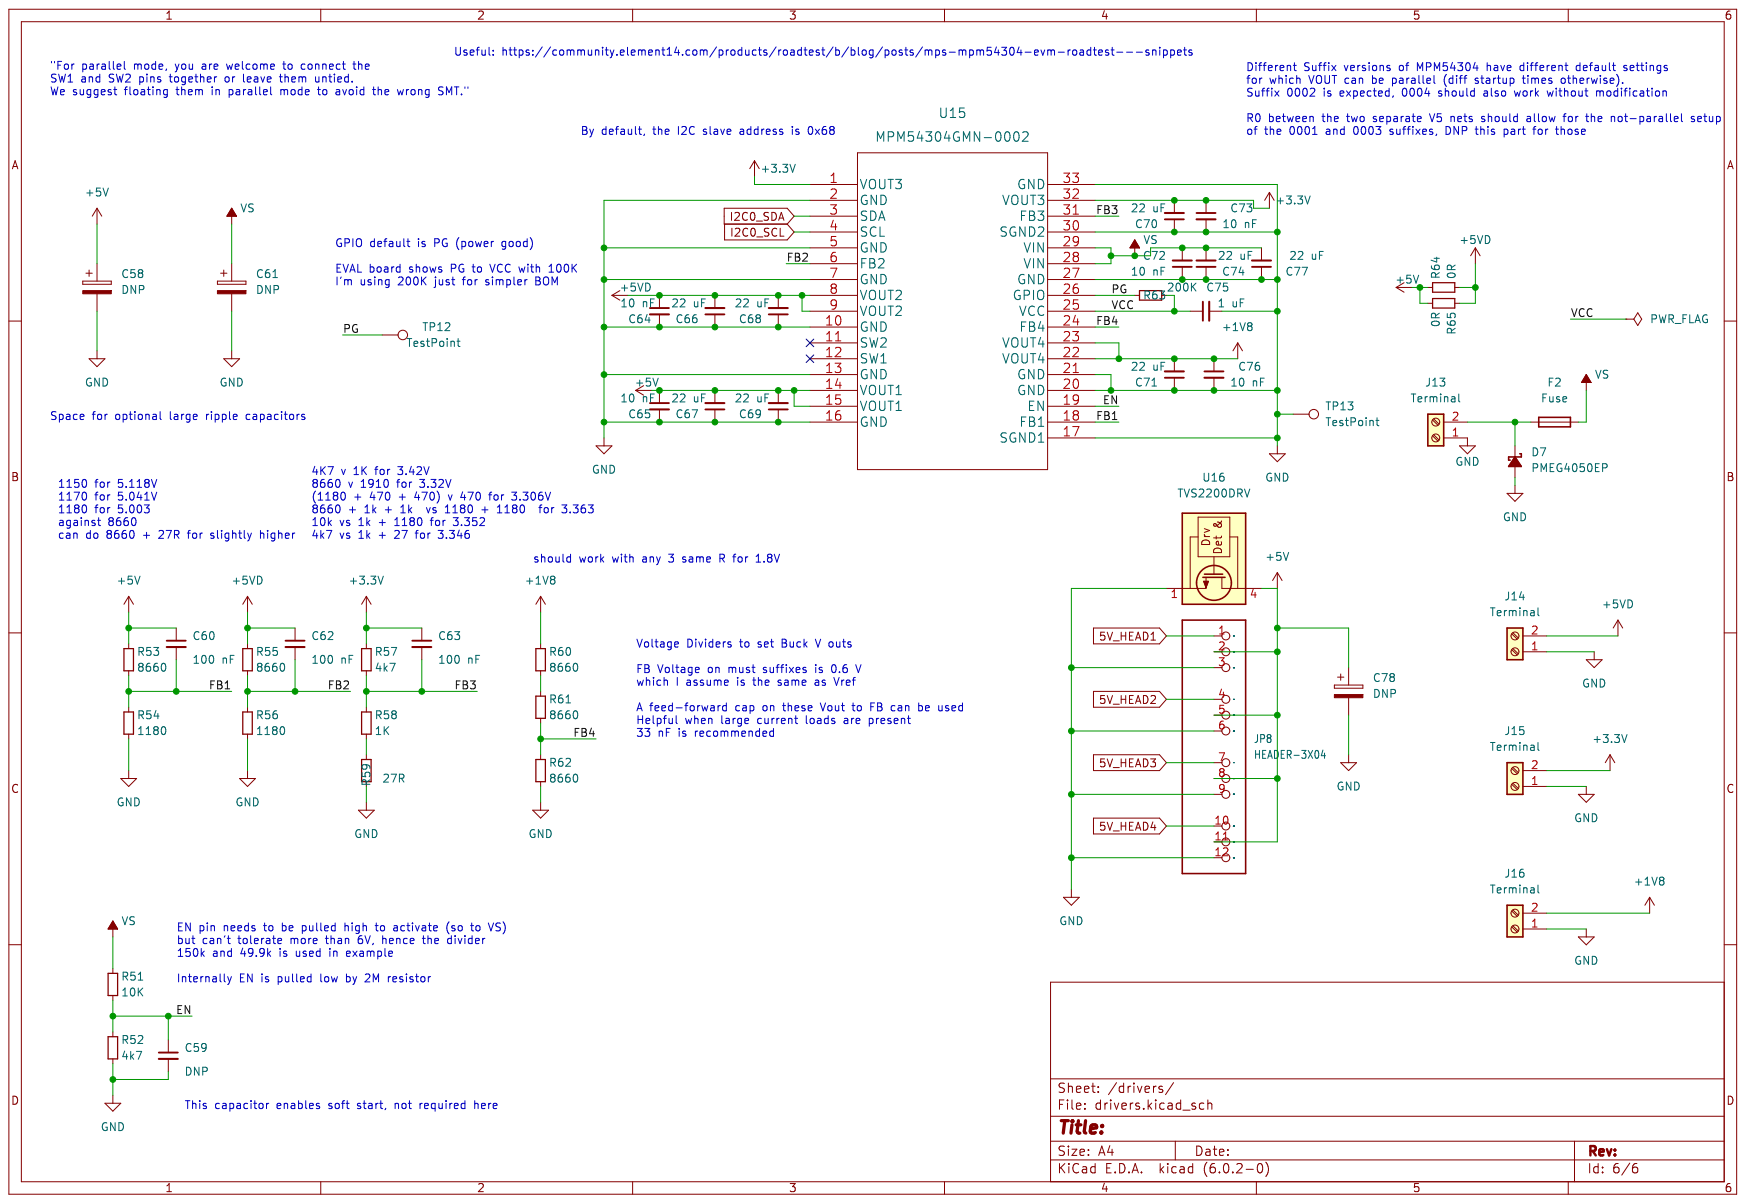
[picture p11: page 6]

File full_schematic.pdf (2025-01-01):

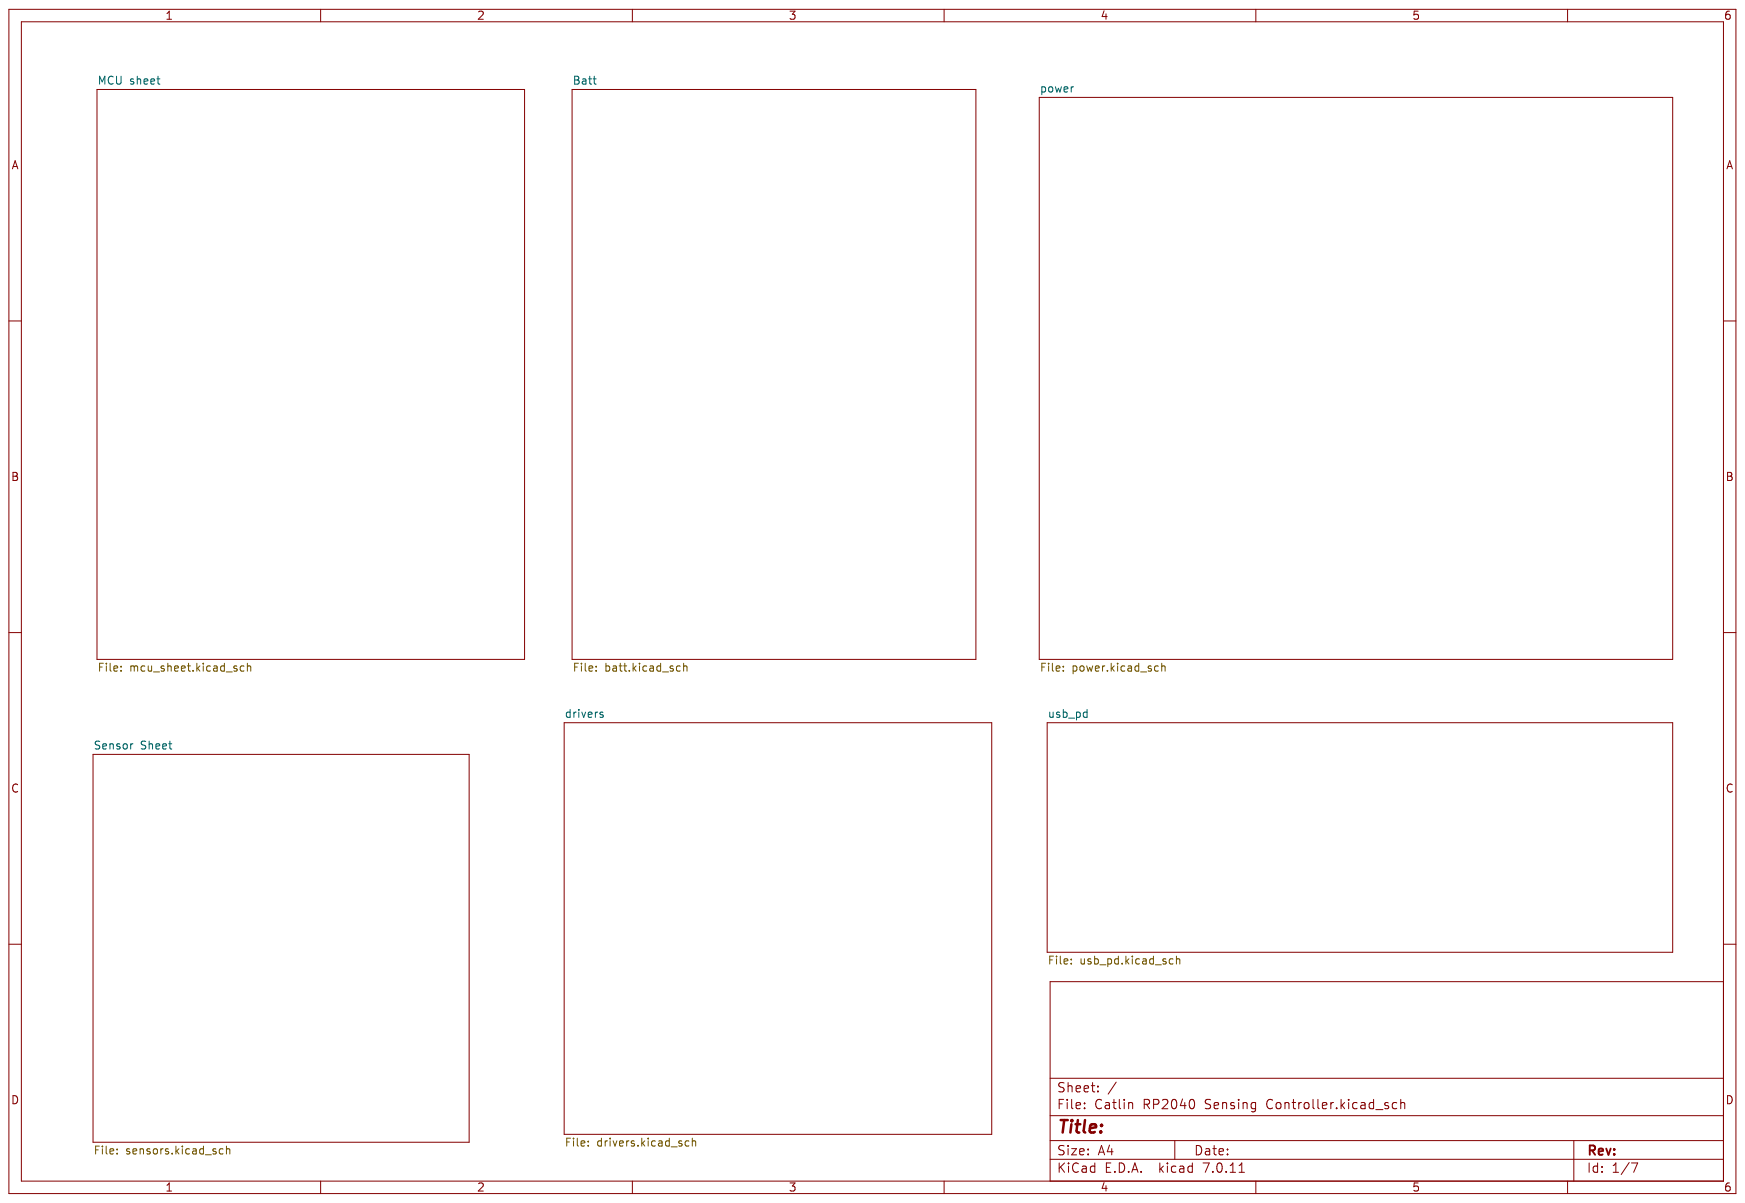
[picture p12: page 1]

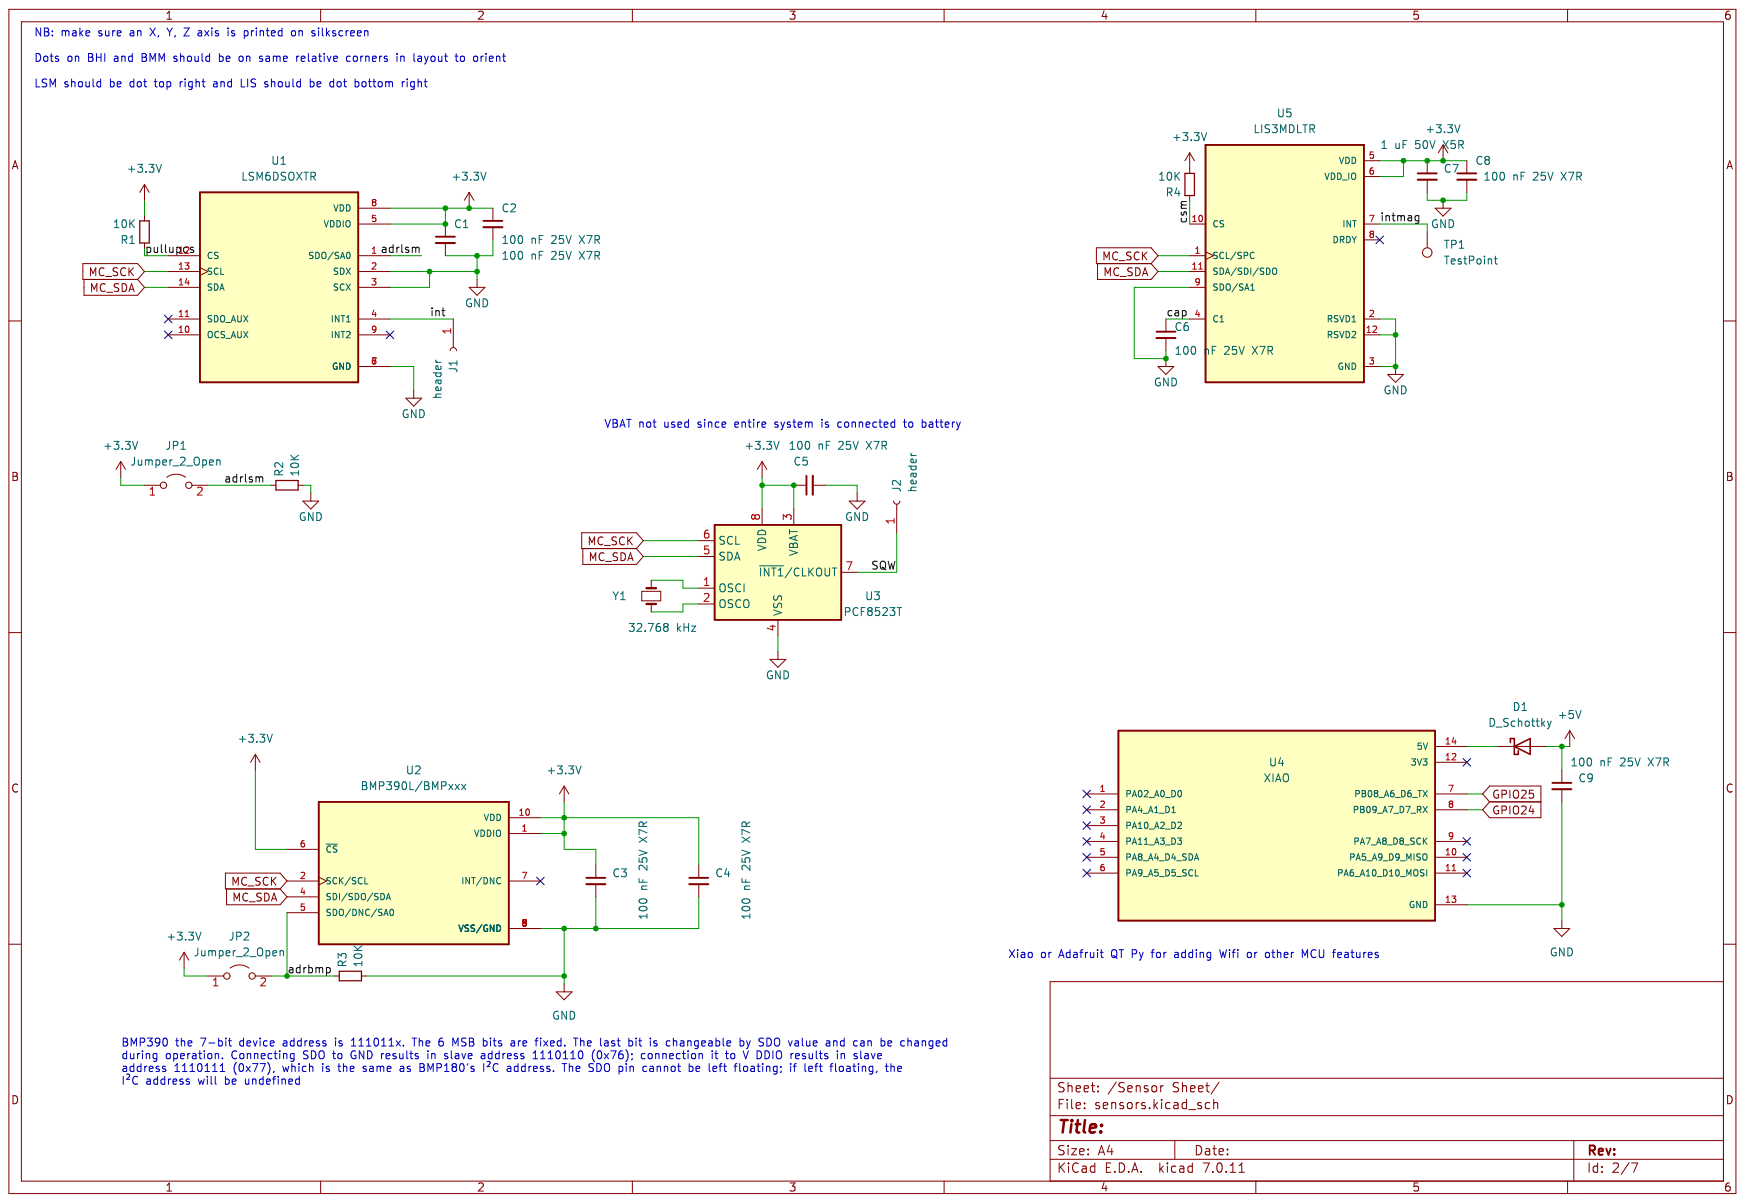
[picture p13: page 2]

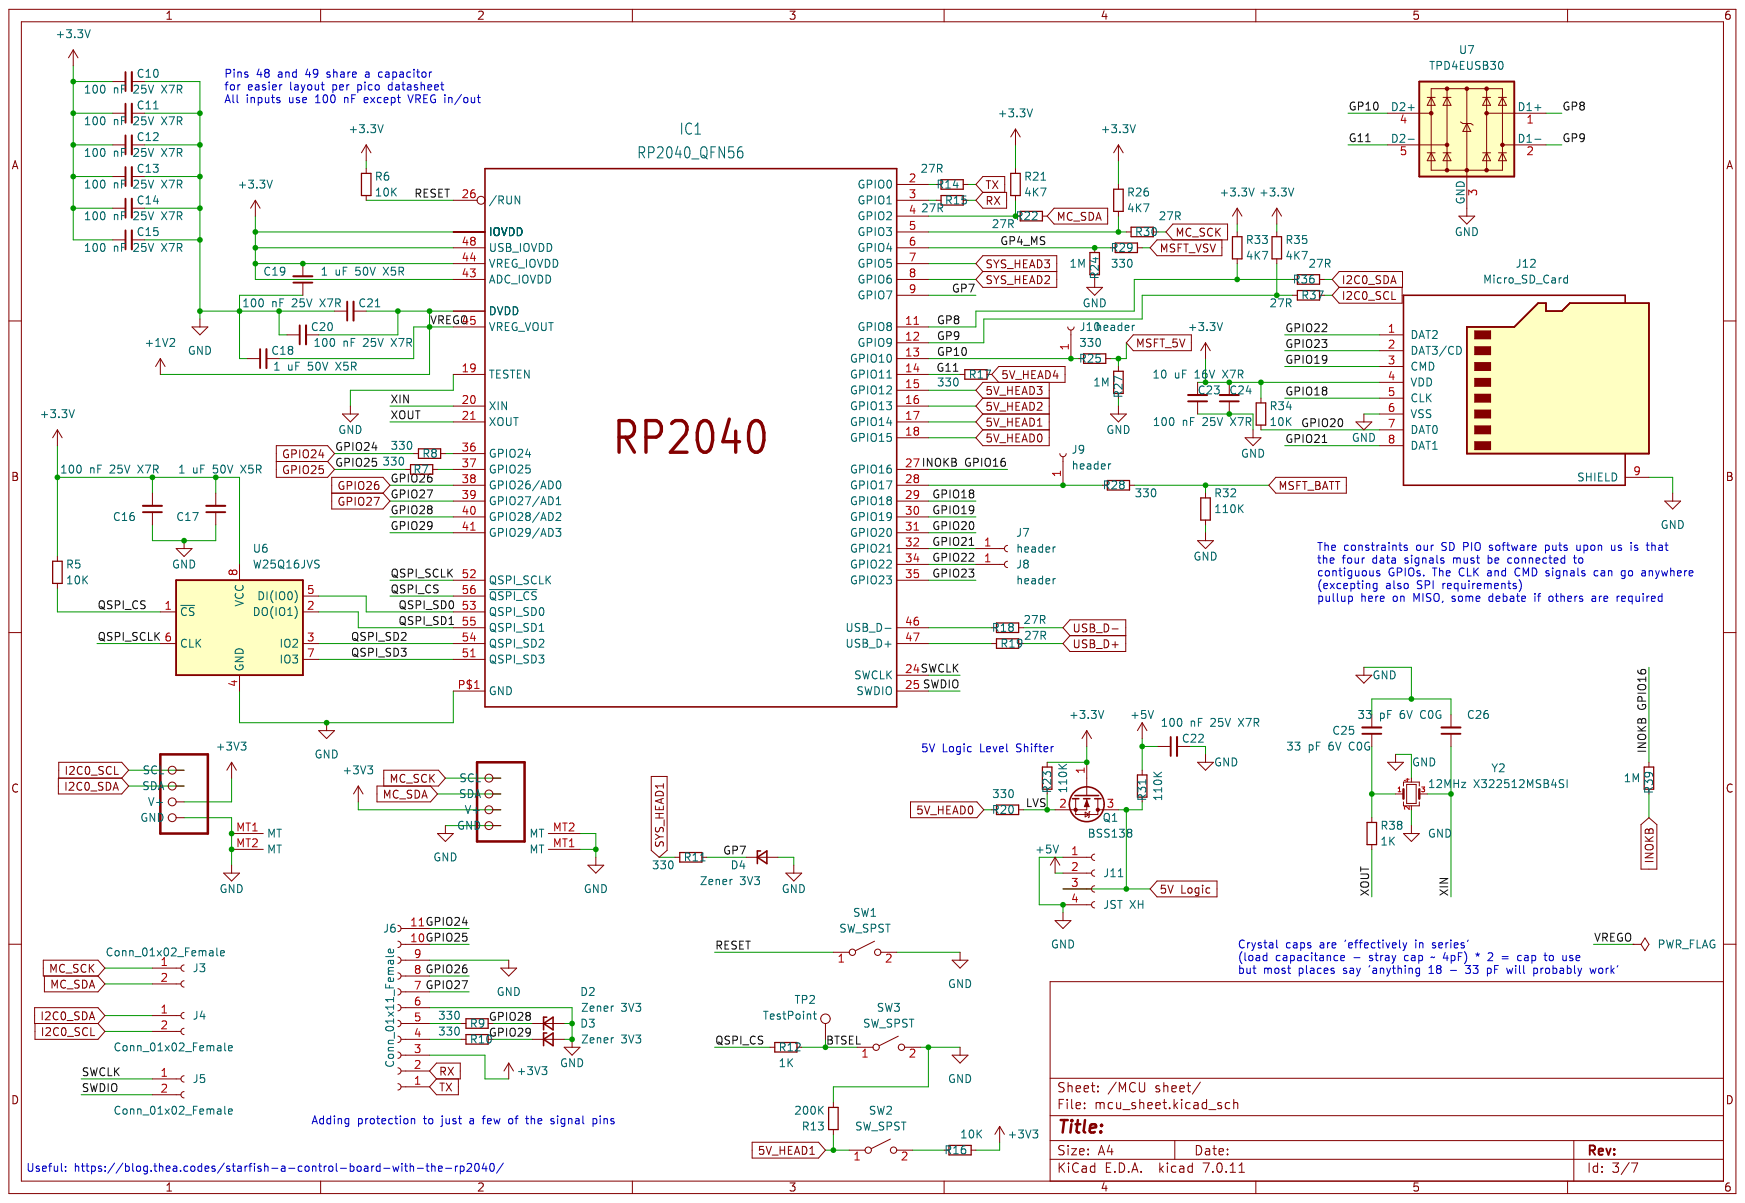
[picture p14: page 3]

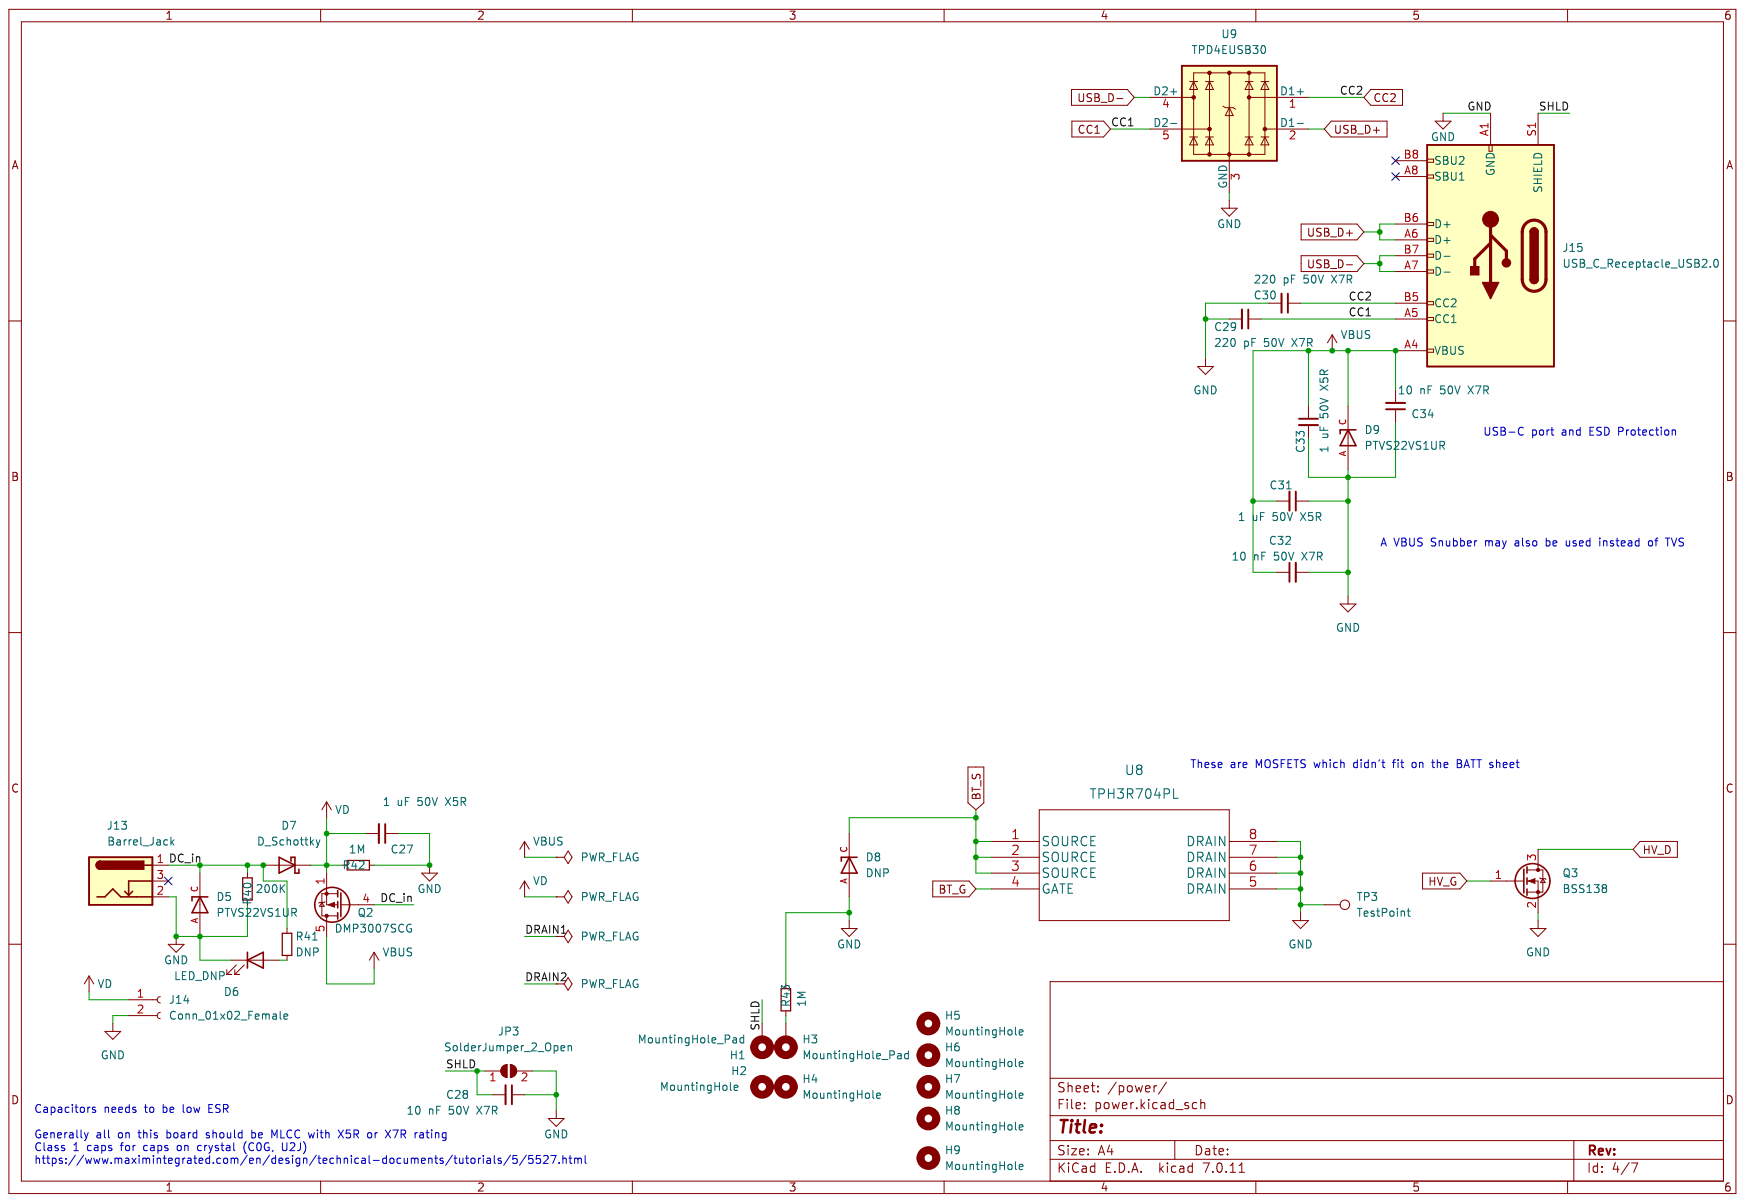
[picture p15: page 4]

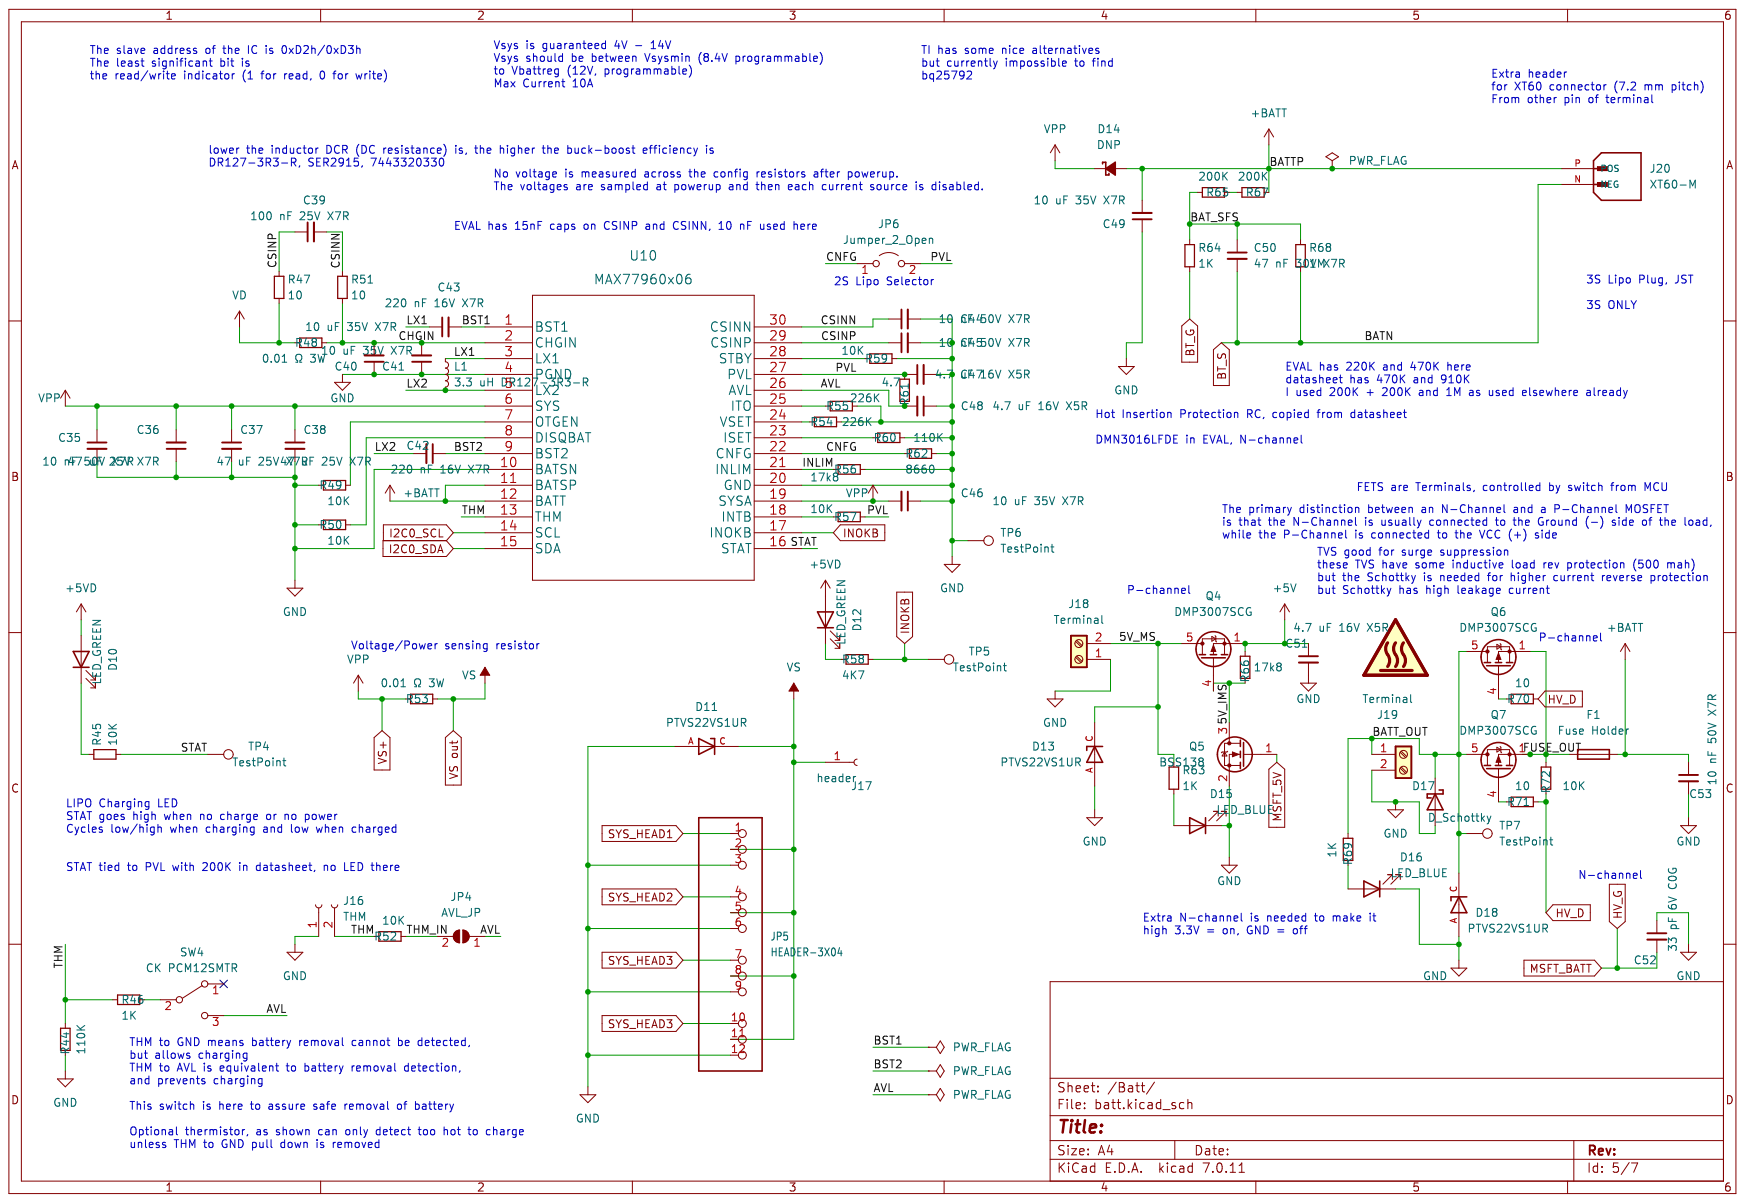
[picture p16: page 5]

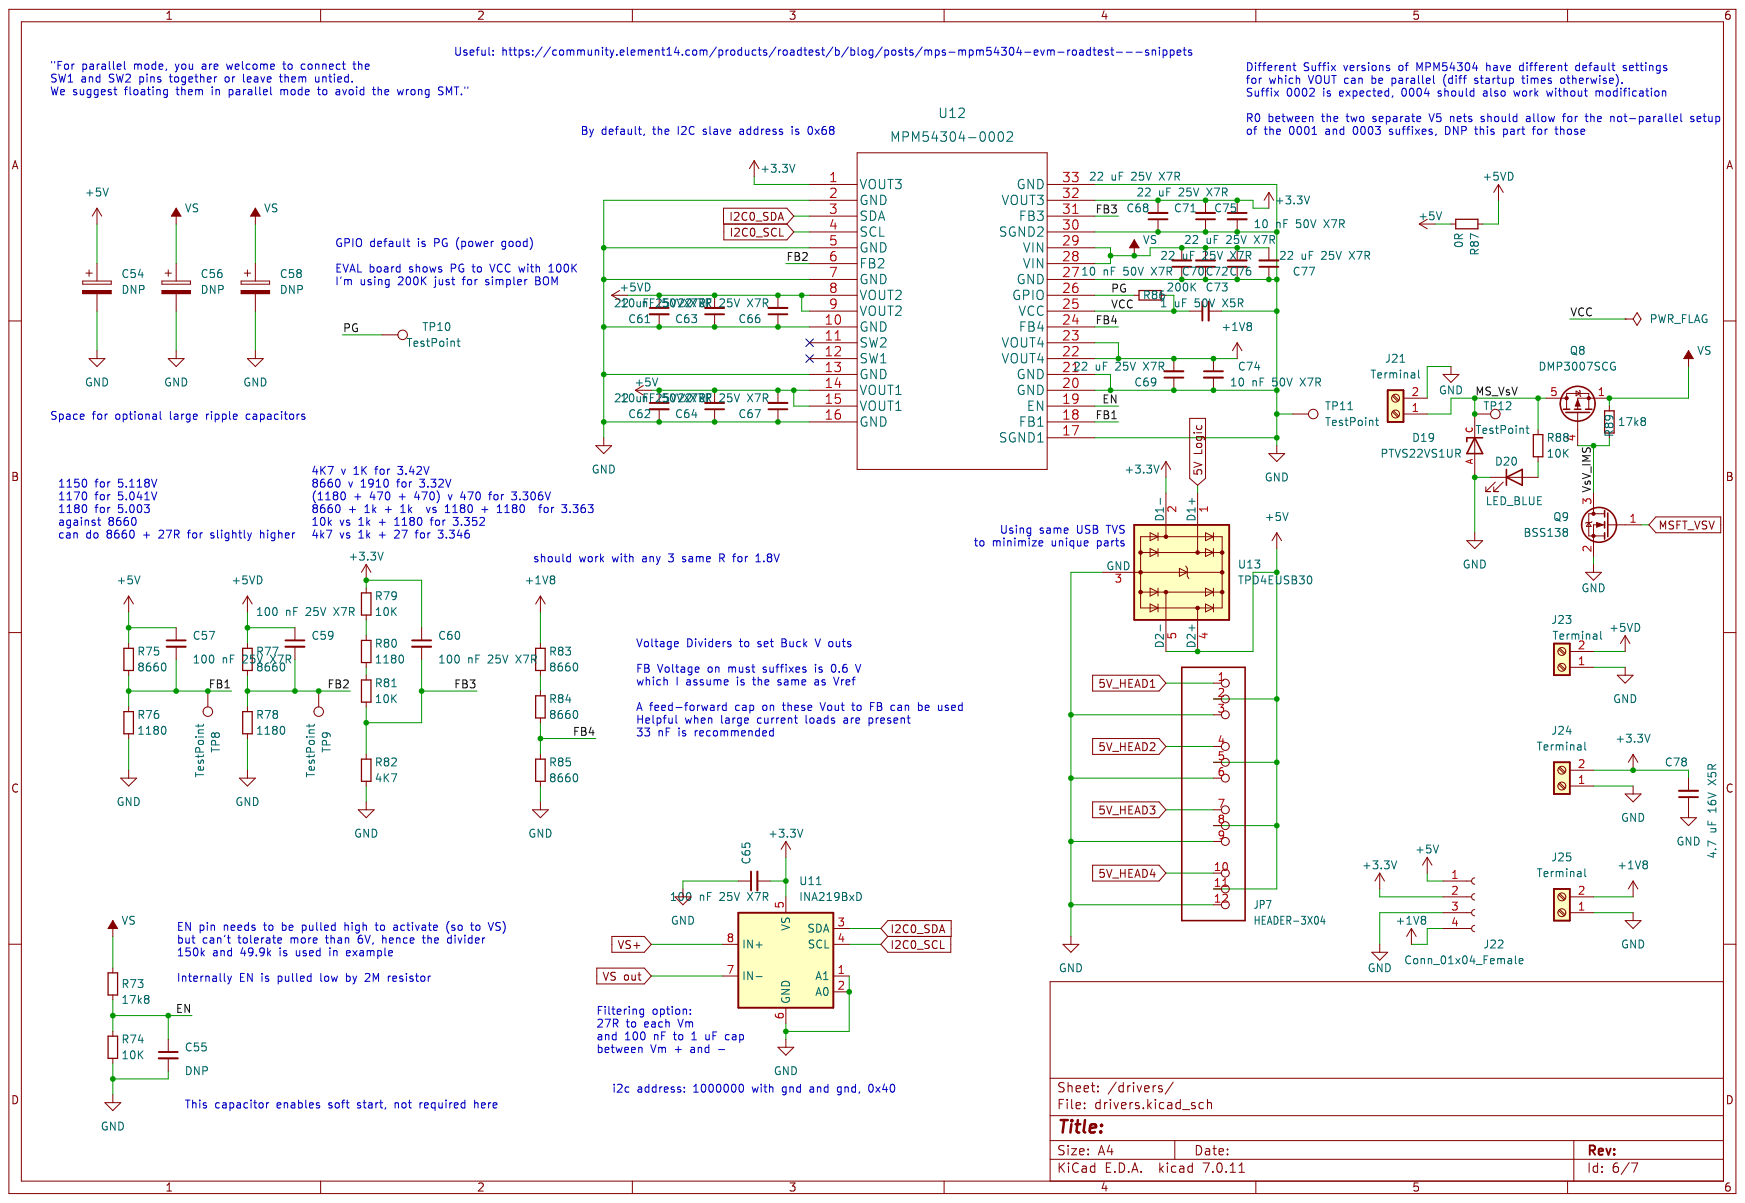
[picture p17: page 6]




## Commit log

2025-01-01 production version (2023)
    [Catlin RP2040 Sensing Controller-B_Cu.gbr, Catlin RP2040 Sensing Controller-B_Mask.gbr, Catlin RP2040 Sensing Controller-B_Silkscreen.gbr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]
2025-01-01 add bom and cpf from production version
    [catlin_rp2040_cpf_20230625.csv, catlin_rp2040_jcl_bom_20230625_subset.csv]
